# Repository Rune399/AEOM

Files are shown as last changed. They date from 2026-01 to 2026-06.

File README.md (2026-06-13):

<p align="left">
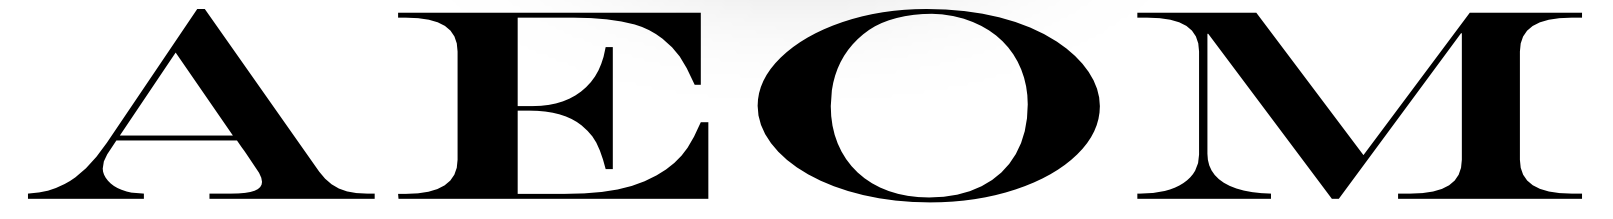
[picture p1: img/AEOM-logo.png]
  
</p> 

AEOM, de slimme interface die gezinnen helpt zonne-energie optimaal te gebruiken en hun enrgieverbruik beter te begrijpen.

🛠️ Built by ``Miro Mangelschots`` & ``Kylian Maelstaf`` & ``Rune Coppieters``  
🔥 Supervised by ``prof. dr. Bas Baccarne``, ``Yannick Christiaens`` & ``Wouter Devriese``    
🌱 Grown at ``Ghent University`` 🏛️ ``Industrial Design Engineering`` ([project overview](https://github.com/basbaccarne/human-centered-design)) 

19/01/2026   

## Samenvatting

Gebruikers hebben soms nood aan functionaliteiten die hun huishoudtoestellen niet hebben. Hoewel er steeds meer slimme apparaten op de markt komen, zijn deze vaak duur en is het vervangen van een perfect werkend toestel voor veel mensen niet de moeite waard.

Om dit probleem op te lossen werd **AEOM** ontwikkeld.

Dit project begon oorspronkelijk als een oplossing voor eigenaars van zonnepanelen die hun opgewekte energie optimaal wilden benutten. Tijdens het ontwerpproces bleek echter dat de onderliggende behoefte breder was: gebruikers willen bestaande apparaten automatiseren zonder deze te vervangen. Daarom verschoof de focus naar het slim maken van zogenaamde **"domme" apparaten**, met een specifieke focus op wasmachines en droogkasten.

### Voorbeelden van toepassingen

- Een wasmachine automatisch starten wanneer de energieprijs het laagst is.
- Een droogkast laten draaien wanneer er voldoende zonne-energie beschikbaar is.
- Een wasprogramma starten zodat het klaar is wanneer de gebruiker thuiskomt.
- Bestaande toestellen integreren in een slimme woning zonder nieuwe apparaten aan te kopen.

### De oplossing

AEOM is een modulair systeem dat fysieke knoppen en draaiknoppen van bestaande apparaten automatisch kan bedienen. Hierdoor kunnen huishoudtoestellen geautomatiseerd worden zonder aanpassingen aan het toestel zelf.

✨ Automatiseert bestaande apparaten zonder demontage.

⚙️ Bedient fysieke knoppen en draaiknoppen automatisch.

📱 Configureerbaar via een gebruiksvriendelijke applicatie.

🔔 Ondersteunt meldingen en statusupdates.

🔄 Herbruikbaar op verschillende toestellen.

Door bestaande apparaten slimmer te maken in plaats van ze te vervangen, biedt Orion een toegankelijke en duurzame manier om meer comfort, automatisering en controle in huis te brengen.
<!--Gebruikers hebben soms nood aan functionaliteit, die hun apparaten niet hebben. Nieuwe "slimme" apparaten bestaan, maar zijn vaak duur. Het is dan ook voor veel mensen niet de moeite om daarvoor een nieuwe machine te kopen. Om dat probleem op te lossen werd *AEOM* ontwikkeld.

Dit project is begonnen als oplossing voor zonnepaneel-houders, die optimaal gebruik willen maken van hun zonne-energie. 
Uiteindelijk is dat echter verandert, naar het automatiseren van "domme" apparaten. Met een focus op wasmachines en droogkasten.

>Voorbeeld van een toepassing:
>De was starten op het meest economische moment van de dag. Of op het juiste moment, zodat die klaar is wanneer de gebruiker thuis komt... 

De oplossing is een slim systeem dat apparaten aan en uit schakelt op basis van parameters, die de gebruiker instelt.

<!--Zonnepaneel-houders kunnen de goedkopere energie niet optimaal gebruiken, omdat ze overdag werken. Bestaande oplossingen zijn grote investeringen.

Dit probleem werd onderzocht aan de hand van literatuuronderzoek, interviews met de gebruikers en gebruikerstests.

De oplossing is een slim systeem dat apparaten aan en uit schakelt, op basis van de geproduceerde zonne-energie. Daarbij houd het rekening met ingestelde prioriteiten en limieten.

Het systeem regelt meerdere apparaten automatisch, waardoor de opgewekte zonne-energie optimaal kan verbruikt worden. En dat zonder de gebuiker, die zich er mee bezig moet houden.

>:bulb:Voor simpele apparaten, worden slimme pluggen geintegreerd. Hiervoor worden bv. de bestaande pluggen van [Shelly](https://www.shelly.com/products/shelly-plug-s-gen3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) gebruikt.

>:zap:Voor complexere apparaten, zoals wasmachines, wordt een nieuw onderdeel ontwikkelt. De bedoeling van dat onderdeel is om draaiknoppen en touchscreens te kunnen bedienen.

<p align="center">
  <img src="img/Hero1.png" width="100%">
</p>-->
<p align="center">
  
</p>

## Introductie

De opkomst van hernieuwbare energie, zoals zonnepanelen, zorgt voor nieuwe uitdagingen in huishoudelijk energiegebruik. Hoewel energie lokaal wordt geproduceerd, slagen gebruikers er vaak niet in om hun verbruik af te stemmen op deze productie, wat leidt tot inefficiëntie en verlies van potentieel voordeel.

Bestaande oplossingen, zoals slimme toestellen, vereisen doorgaans een aanzienlijke investering en vervangen bestaande apparaten. Dit maakt ze voor veel gebruikers minder toegankelijk.

AEOM vertrekt vanuit een alternatieve benadering: het slim maken van bestaande, “domme” toestellen via een externe interface. Door apparaten automatisch aan te sturen op basis van parameters zoals energieproductie, kost en gebruikscontext, maakt AEOM efficiënter en bewuster energiegebruik mogelijk zonder ingrijpende veranderingen in de bestaande huishoudcontext.

Dit dossier beschrijft hoe dit concept tot stand kwam, met nadruk op de onderbouwing van ontwerpkeuzes via gebruikersonderzoek, iteratie en technische validatie.

## Inhoudstafel

1. [Methodologie](./docs/Methodologie.md)
2. [Discovery](./docs/1_Discovery.md)
3. [Defintion](./docs/2_Definition.md)
4. [The pivot](./docs/3.1_The_Pivot.md)
5. [Develop 1](./docs/3_Develop_1.md)
6. [Develop 2](./docs/4_Develop_2.md)
7. [Develop 3](./docs/5_Develop_3.md)
8. [Design Requirements](./docs/Design_requirements.md)
9. [Bill of materials](./docs/BOM.md)
10. [Handleiding voor laatste prototype](./docs/Manual.md)

# Conclusie

Tijdens dit project werd onderzocht hoe bestaande huishoudtoestellen slimmer gemaakt kunnen worden zonder deze te vervangen. Uit gebruikersinterviews, benchmarkonderzoek, technische experimenten en meerdere iteraties van prototyping bleek dat veel gebruikers nood hebben aan extra functionaliteiten, zoals automatisering en slim energiebeheer, maar niet bereid zijn om hiervoor nieuwe toestellen aan te kopen.

Het finale concept, **AEOM**, is een universeel automatiseringsplatform dat fysieke knoppen en draaiknoppen van bestaande apparaten automatisch kan bedienen. Hierdoor kunnen toestellen zoals wasmachines en droogkasten geïntegreerd worden in slimme automatiseringsscenario's zonder enige aanpassing aan het toestel zelf.

Het concept bestaat uit een positioneerbare arm die zich naar de gewenste knop beweegt en deze fysiek bedient. Via een mobiele applicatie kan de gebruiker toestellen configureren, automatiseringen instellen en meldingen ontvangen. Hierdoor wordt functionaliteit toegevoegd aan bestaande apparaten, terwijl hun oorspronkelijke werking volledig behouden blijft.

Wij geloven dat **AEOM** de best mogelijke oplossing is voor het gestelde probleem omdat het verschillende voordelen combineert die tijdens het onderzoek consequent als belangrijk naar voren kwamen:

- Geen vervanging van bestaande toestellen nodig.
- Compatibel met een brede waaier aan huishoudtoestellen.
- Eenvoudig te installeren zonder demontage of technische kennis.
- Herbruikbaar op verschillende apparaten.
- Lagere kost dan de aankoop van nieuwe slimme toestellen.
- Behoud van volledige controle door de gebruiker.
- Mogelijkheid om toekomstige functionaliteiten via software uit te breiden.

Bovendien werden gedurende het ontwikkelproces verschillende alternatieve oplossingen onderzocht, waaronder slimme stekkers, vaste interfaces, meerdere actuatorconfiguraties, verschillende bevestigingsmethoden en uiteenlopende positioneringsmechanismen. De uiteindelijke combinatie van een **sliding & rotating arm**, een **servogestuurde knopbediening** en een **modulaire mobiele interface** behaalde consequent de beste resultaten op vlak van gebruiksgemak, betrouwbaarheid, universaliteit en gebruikersacceptatie.

De ontwerpkeuzes zijn gebaseerd op de verzamelde onderzoeksresultaten en voldoen aan de vooropgestelde [Design Requirements](./Design_Requirements.md). Hierdoor vormt **AEOM** een technisch haalbare, gebruiksvriendelijke en toekomstgerichte oplossing voor het automatiseren van bestaande huishoudtoestellen.

<p align="center">
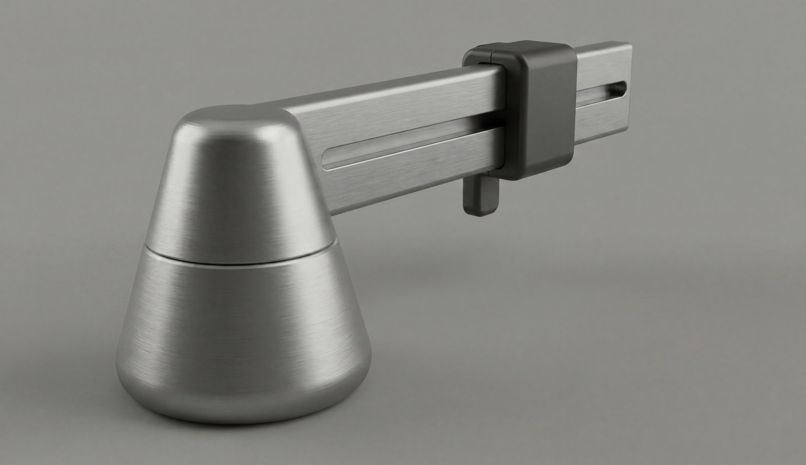
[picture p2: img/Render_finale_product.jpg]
  
</p>

## Kritische reflectie

Bij de define fase bleek het een uitdaging te zijn, om ons op het juiste pad te houden en niet de mist in te wandelen. We vergaten soms dat de in de define fase zaten, waar het de bedoeling is om oplossingen voor het probleem te zoeken.

We hebben eerst onderzoek gedaan naar de meest intuitieve layout van een scherm-interface. Dit onderzoek had bij nader inzien beter gepast bij de develop fase.
In het komende semester zal het dus belangrijk zijn voor ons om elke les even stil te staan en de vraag te stellen, of wat we mee bezig zijn nog past binnen deze fase...

Bovendien hebben we veel tijd verloren, door in de les te bespreken wat de volgende stappen zijn, waardoor we meerdere, hele lessen weinig hebben gedaan, buiten overlegd. 
Op een bepaald moment twijfelden we over de richting waarin we gingen, we stonden op het punt om een pivot te ondergaan, maar hebben dat uiteindelijk niet gedaan. De oorzaak van deze twijfel was waarschijnlijk dat we juist het interface-onderzoek hadden uitgevoert, dat eigenlijk voor het volgende semester was bedoeld. Door deze pseudo-pivot zijn opniew veel tijd verloren.
Hierdoor hadden we het gevoel dat we heel de tijd achter zaten (wat ook wel zo was) en hebben we ook geen tijd meer gehad om een een tweede onderzoek te doen dat wel goed in de define fase hoort... 

## Noot inzake het gebruik van AI
Om schetsen om te zetten in renders werd "[Vizcom](https://vizcom.com)" gebruikt (o.a. [Hero-shot](img/Hero1.png)).
AI werd ook gebruikt om sommige onderzoeken te verwerken. Hierbij werd opgelet dat **alle info geanonimiseerd** werd **alvorens** AI in te zetten.

## Bijlagen

### Discovery
* Literatuuronderzoek (N=10)
  * [Benchmark protocol](reports%20and%20protocols/S@H_Benchmark%20protocol.pdf)
  * [Benchmark report](reports%20and%20protocols/S@H_Benchmark%20report.pdf)
* Interviews (N=3)
  * [User interview protocol](reports%20and%20protocols/S@H_User%20Interview%20Protocol.pdf)
  * [User interview report](reports%20and%20protocols/S@H_User%20interview%20report.pdf)
    
### Definition
* User testing wave 1 (N=3)
  * [Interface protocol](reports%20and%20protocols/Interface%20protocol.pdf)
  * [Interface repport](reorts%20and%20protocols/Inteface%20report.pdf)
* User testing wave 2 (N=3)
  * [Functies protocol](reports%20and%20protocols/Functies%20protocol.pdf)
  * [Functies repport](reports%20and%20protocols/Functies%20report.pdf)

### Develop 1
* User interview (N=3)
  * [Interview after pivot protocol](reports%20and%20protocols/Interface%20protocol.pdf)
  * [Interview after pivot repport](reports%20and%20protocols/Inteface%20report.pdf)
* Prototype testing (N=~5)
  * [Drukken van knoppen protocol](reports%20and%20protocols/Functies%20protocol.pdf)
  * [Drukken van knoppen report](reports%20and%20protocols/Functies%20report.pdf)

### Develop 2
* Draaien van knoppen (N=3)
  * [Draaien van knoppen protocol](reports%20and%20protocols/2.%20Draaien%20van%20knoppen%20protocol.pdf)
  * [Draaien van knoppen report](reports%20and%20protocols/2.%20Draaien%20van%20knoppen%20report.pdf)
* Machine interface (N=10)
  * [Machine interface protocol](reports%20and%20protocols//4.%20Machine%20interface%20protocol.pdf)
  * [Machine interface report](reports%20and%20protocols//4.%20Machine%20interface%20report.pdf)
* Gebruikersonderzoek (N=5)
  * [Gebruikersonderzoek protocol](reports%20and%20protocols/5.%20Gebruikersonderzoek%20protocol.pdf)
  * [Gebruikersonderzoek report](reports%20and%20protocols/5.%20Gebruikersonderzoek%20report.pdf)
* Bevestigingsmechanismen (N=3)
  * [Bevestigingsmechanismen protocol](reports%20and%20protocols/2.%20Bevestigingsmechanismen%20protocol.pdf)
  * [Bevestigingsmechanismen report](reports%20and%20protocols/2.%20Bevestigingsmechanismen%20report.pdf)
    
### Develop 3
* CMF (N=5)
  * [CMF protocol](reports%20and%20protocols/6.CMF_protocol.pdf)
  * [CMF report](reports%20and%20protocols/6.CMF_report.pdf)

## Licentie

This repository contains both software and design materials created as part of an industrial design energineering project at Ghent University.

- **Software and code:** [MIT License](./LICENSE-MIT)  
- **Design, documentation, CAD, and media:** [CC BY 4.0 License](./LICENSE)
  
You are free to reuse and build upon this work, both commercially and non-commercially, as long as proper attribution is given to the original authors.

<br>

---

<p align="center">
  <a href="/README.md">⬆️ Return to top</a><br>
  <a href="/LICENSE">📜 CC License</a> & <a href="/LICENSE">MIT License</a><br>

</p>

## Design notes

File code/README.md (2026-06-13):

## Code structuur

Deze map bevat de Arduino implementaties voor de aansturing van de verschillende mechanische concepten.  

### **Servo_and_Stepper_code**  
  Code voor de **sliding + rotating arm**  
  - Combineert een **servo motor** (rotatie) met een **stepper motor** (lineaire beweging)  
  - Zorgt voor positionering van de arm in zowel hoek als afstand  
  - Wordt gebruikt voor de finale geselecteerde oplossing  
<p align="left">
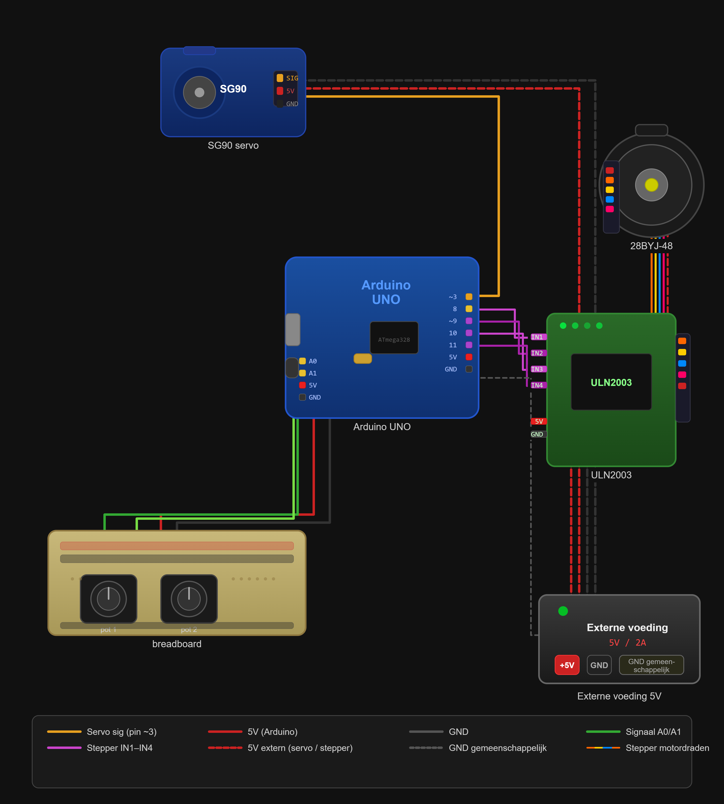
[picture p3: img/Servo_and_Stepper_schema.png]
  
  
### **Servos_code**  
  Code voor de **double pivot arm**  
  - Gebruikt meerdere **servo motoren** voor de verschillende rotatiepunten  
  - Stuurt de arm aan via gecombineerde hoeken (inverse kinematics)  
  - Wordt gebruikt voor het alternatieve concept dat later geëlimineerd werd
    <p align="left">
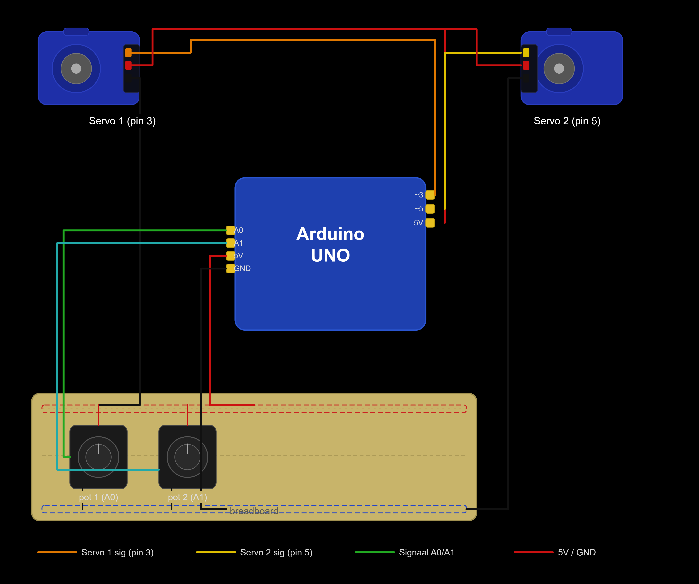
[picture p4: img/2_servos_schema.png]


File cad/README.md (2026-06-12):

## CAD structuur

De CAD-bestanden zijn georganiseerd per mechanisme en per iteratiefase. Dit maakt het mogelijk om de evolutie van het ontwerp en de verschillende prototypes duidelijk te onderscheiden.  

### Opbouw  

- **cad/**  
  Hoofdmap met alle CAD-bestanden  

  - **rotating pivot arm/**  
    Ontwerpen van het rotating pivot arm mechanisme  

    - **V1/**  
      Eerste generatie prototypes  
      → Snelle exploratie van concept en werking  

    - **V2/**  
      Tweede generatie prototypes  
      → Verbeterde ontwerpen op basis van testen (stabiliteit, haalbaarheid, gebruik)  

    - **arm_close.3mf**  
      Configuratie waarbij de arm dicht bij het centrum staat  

    - **arm_far.3mf**  
      Configuratie waarbij de arm maximaal is uitgeschoven  

    - **base.3mf**  
      Basismodel van de structuur waarop de arm gemonteerd wordt  

    - **fullprint.3mf**  
      Volledige samenstelling, klaar voor 3D-print  

    - **test belt afstanden.3mf**  
      Testmodel om verschillende riemafstanden en transmissies te evalueren  

  - **rotating slider arm/**  
    Ontwerpen van het sliding + rotating arm mechanisme  

    - **V1/**  
      Eerste generatie prototypes  
      → Initiële exploratie van sliding mechanisme  

    - **V2/**  
      Tweede generatie prototypes  
      → Geoptimaliseerde ontwerpen gebaseerd op testen en iteraties

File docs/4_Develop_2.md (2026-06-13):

## Develop 2

### Doelstellingen
In de vorige de develop 1 fase werd een schema met human-product-interactie's opgesteld. Daar werd ook voor elke subfunctie oplossingen bedacht.

In deze fase moet verder onderzoek en tests gedaan worden om de beste deeloplossingen te selecteren.

Er wordt ingegaan op volgende deelfuncties:
- Draaien van knoppen
- Machine interface =  instellen van de interactie-locatie
- Bevestigingsmechanismen
<br><br><br>
### Methoden
#### 1. Draaien van knoppen
Bij het besturen van een draaiknop komen er twee hoofdzaken naar boven:
•	Welke actuator zullen we gebruiken?
•	Hoe gaan we de draaiknop manipuleren?
<br><br>

##### Actuator
<p align="left">
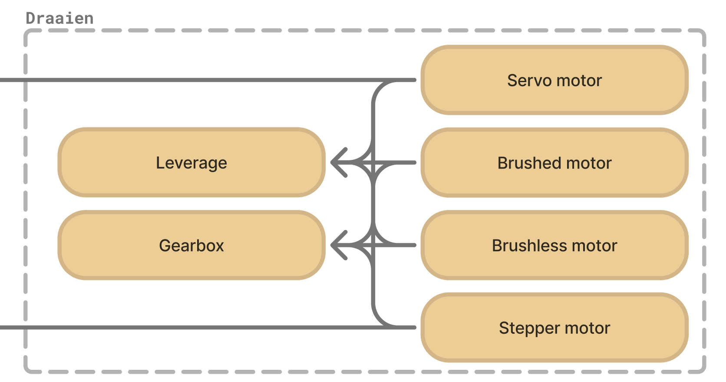
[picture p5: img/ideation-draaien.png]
  
</p>

1.	Ideeën generatie actuatoren
2.	De resultaten van vorig onderzoek, die nuttig zijn, worden gebruikt om actuatoren te elimineren
3.	Kracht servo apart uittesten op de knop*
4.	Er wordt één finale actuator gekozen

> [!NOTE]
>*Een servo is eigenlijk opgebouwd uit een geborstelde DC motor en tandwielkast met toevoeging van één of andere sensor.
>Omdat die feedback van een sensor in deze toepassing belangrijk is, zou het makkelijker zijn, om de servo te gebruiken. Daarvoor moet de servo echter sterk genoeg zijn om de knop te kunnen draaien. Voor die reden wordt de servo nog eens apart uitgetest op de knop.

<br>

##### Manipulatie draaiknop
<p>
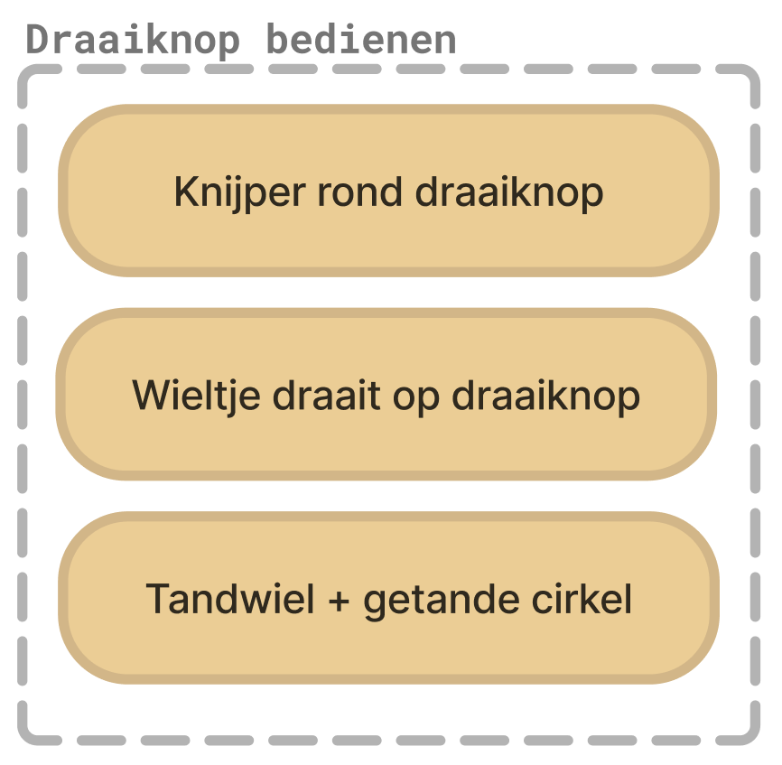
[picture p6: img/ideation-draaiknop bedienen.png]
  <br>1.	Ideeën generatie om de knop te kunnen manipuleren<br>
  2.	Er worden prototypes gemaakt voor de verschillende ideeën<br>
  3.	De prototypes worden uitgetest op de draaiknop van een wasmachine (beiden worden aangestuurd met hetzelfde handvat)<br>
  4.	De voordelen en nadelen van elk idee worden opgesomd<br>
  5.	De ideeën worden vergeleken en er wordt één idee uitgekozen<br>
  <br>
  Voor meer detail over dit onderzoek of een blik op de gebruikte prototypes, zie <a href="../reports and protocols/2. Draaien van knoppen protocol.pdf">Draaien van knoppen protocol</a>.
</p>
<br clear="left" />
<br><br>

#### 2. machine interface onderzoek
<p align="left">
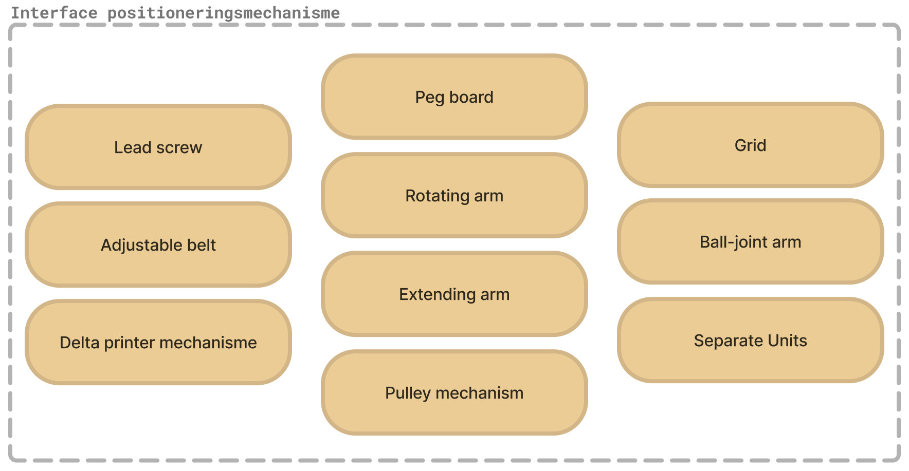
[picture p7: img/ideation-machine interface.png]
  
</p>
  
#### Deel 1: eerste eliminatie.
De ideeën worden vergeleken via een keuzematrix
<br>
#### Deel 2: prototype + vergelijkend testen.
1.  Er worden prototypes gemaakt voor de overblijvende ideeën
2.  De prototypes worden op een wasmachine geplaatst om te testen of het systeem aan alle nodige knoppen kan
  
#### Deel 3: technisch uitwerking + gebruikerstesten.
1.  De prototypes worden verder uitgewerkt tot meer afgewerkte versies
2.  De prototypes worden ingezet in een Wizard of Oz testing met gebruikers (N = 5)
3.  De oplossingen worden vergeleken en er wordt één mechanisme geselecteerd

Tijdens de Wizard of Oz testing wordt ook geëvalueerd hoe gebruikers de arm kunnen instellen, waarbij per ontwerp en per methodiek wordt nagegaan hoe intuïtief en efficiënt de sturing verloopt.  
Elke gebruiker voert volgende taken uit:  
- Instellen van de arm met sliders  
- Instellen van de arm met joystick  
- Aanduiden van een knop via een foto  

De interface waarop deze methodes getest worden is hier terug te vinden:  
https://peppy-sprinkles-e374be.netlify.app/  

Na elke test wordt een SUS (System Usability Scale) ingevuld per methodiek en per ontwerp.  
Op het einde volgt een kort interview (QAP) om aanvullende inzichten en opmerkingen te verzamelen.

Voor meer detail over dit onderzoek of een blik op de gebruikte prototypes, zie <a href="../reports%20and%20protocols/4.%20Machine%20interface%20protocol.pdf">Machine interface protocol</a> en <a href="../reports%20and%20protocols/5.%20Gebruikersonderzoek%20Protocol.pdf">Gebruikersonderzoek protocol</a>.

<br><br>
#### 3. bevestigingsmechanismen
<p align="left">
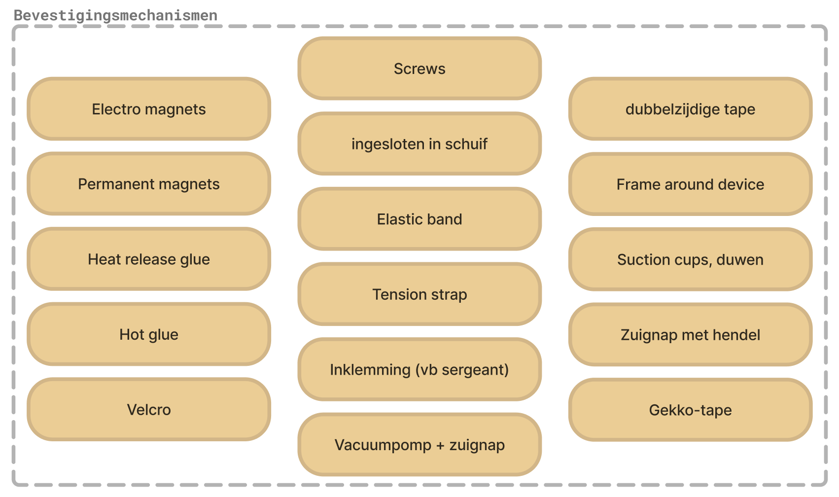
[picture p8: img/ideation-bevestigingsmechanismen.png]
  </p>
  
##### Deel 1: eerste intuïtieve eliminatie.

##### Deel 2: prototyping + vergelijkend testen.
1.	Modulair prototypen
2.	Op wasmachine hangen
3.	Met weegschaal aan het prototype trekken tot het los komt
4.	Filmen bij hoeveel kg kracht het bevestigingsmechanisme lost
5.	Maximale kracht opmeten voor trek en moment voor elke oplossing
6.	Per oplossing 4 tests uitvoeren: 2x trek & 2x moment
7.	Tabel opstellen en gemiddeldes van trek en moment per oplossing berekenen
8.	Grafiek opstellen

Voor meer detail over dit onderzoek of een blik op de gebruikte prototypes, zie <a href="../reports and protocols/2. Bevestigingsmechanismen protocol.pdf">Bevestigignsmechanismen protocol</a>.

<br clear="left" />

### Resultaten
#### 1. Draaien van knoppen

##### a. Vergelijking actuatoren
||Kracht|Gewicht|Gemak aansturing|Feedbackloop|
|--:|:--:|:--:|:--:|:--|
|**Servo**|Matig|Matig|Matig|Ja => hoge precisie + herhaalbaarheid|
|**Stepper**|Matig|Zwaar|Moeilijk|Nee (Maar hoge precisie + herhaalbaarheid, bij geen slip)|
|**Brushed + gearbox**|Zeer hoog|Zwaar|Makkelijk|Nee|

> [!NOTE] 
>stepper niet uitgetest op machine #TODO

##### b. Extra servo test

><a href="../reports and protocols/3. Bevestigingsmechanismen protocol.pdf"><b>Servo_draaien knoppen.mp4</b></a><br>
>De servo had niet genoeg kracht om zelfstandig te knop te draaien, maar er was niet veel extra kracht vereist. Er werd niet getest met een sterkere servo-motor, maar er kan vanuit gegaan worden dat grotere servo-motoren wel de knop zouden kunnen draaien.

##### c. Pros & Cons manipulatie draaiknop
###### Knijper rond draaiknop
<p >
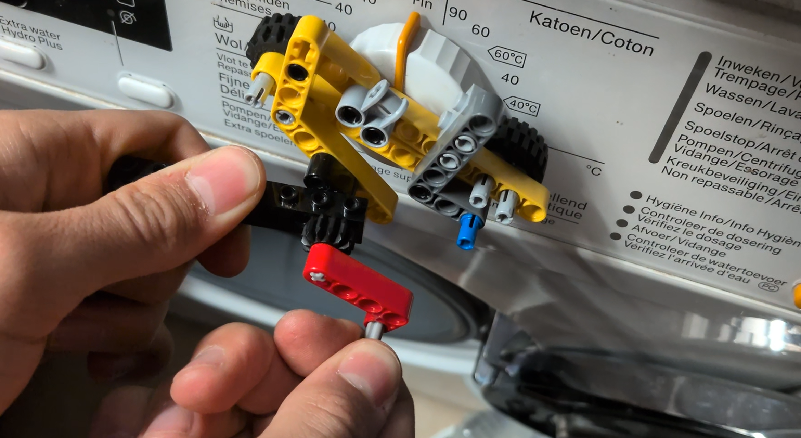
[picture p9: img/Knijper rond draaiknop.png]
  
</p>

✅ Er is veel grip door de instelbare klemkracht<br>
✅ Geen perfect ronde vorm nodig<br>
✅ Uitstekende vormen zijn geen probleem<br>
✅ Eenvoudige constructie<br>

❌ Er is meer kracht nodig dan de andere concepten omdat er geen overbrenging aanwezig is (as motor = as knijper, zonder overbrenging)<br>

<br clear="left" />

###### Wieltje tegen draaiknop
<p >
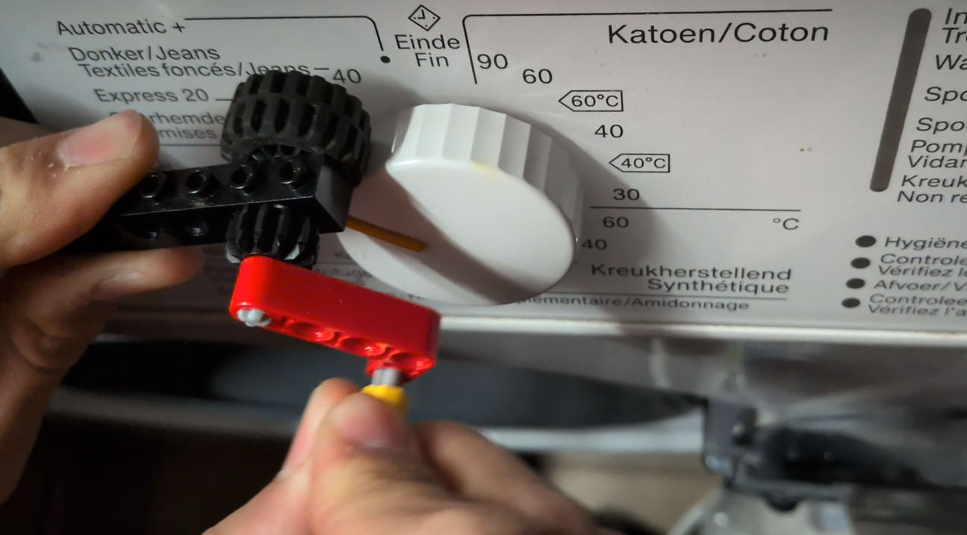
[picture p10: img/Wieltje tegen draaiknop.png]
  
</p>

✅ Voordelige overbrenging, die de nodige kracht van de motor verminderd: door het verschil in diameter tussen het kleine wieltje en de grotere draaknop verminderd de aandrijfkracht.<br>
✅ Het is een zeer compacte oplossing<br>
✅ Eenvoudige constructie en montage<br>

❌ Weinig grip, waardoor er slip aanwezig is en de draaiknop **onbetrouwbaar of niet zal roteren**<br>
❌ **Werkt enkel** goed **met één vorm**: een perfect ronde cirkel, zonder uitstekende delen<br>

<br clear="right" />

###### Vertanding op draaiknop met een tandwiel
<p>
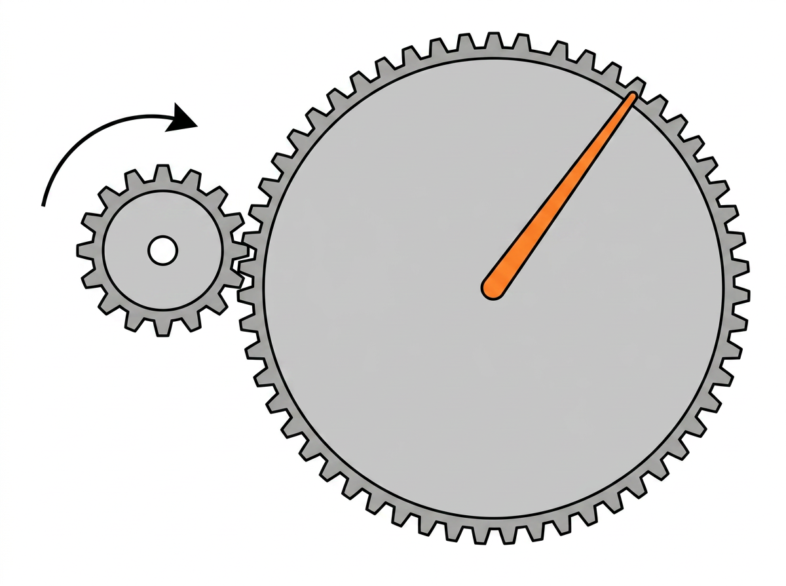
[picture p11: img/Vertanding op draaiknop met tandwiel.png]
  
</p>

✅ Er is een overbrenging aanwezig wat de nodige kracht van de motor verminderd.<br>
✅ Het is een compacte oplossing<br>

❌ Kans op slip tussen tandwielring en draaiknop<br>
❌	Niet zo universeel:<br>
-→ ❌ Werkt enkel goed met één vorm: een perfect ronde cirkel<br>
-→ ❌ Uitstekende delen van de draaiknop zorgen voor problemen<br>
-→ ❌ Verschil in knopdiameter tussen toestellen zorgt voor compatibiliteitsproblemen<br>
<br clear="left" />
<br><br>

#### 2. Machine interface onderzoek

##### a. Eerste eliminatie

|  | || **Peg board** | **Grid** | **Sliding + rotating arm** | **Rotating pivot arm** | **Lead screw carriage** | **Rail + slide carriage** | **Seperate units** | **Standing carriage** | **Spider arms** |
|:---:|:---:|:--:|:---:|:---:|:---:|:---:|:---:|:---:|:---:|:---:|:---:|
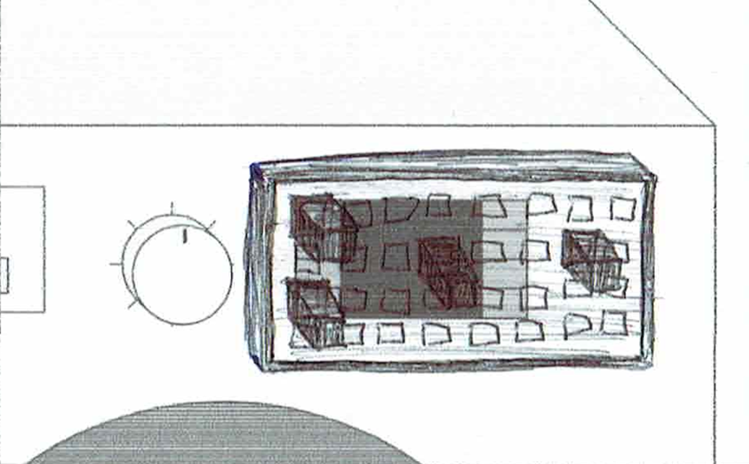
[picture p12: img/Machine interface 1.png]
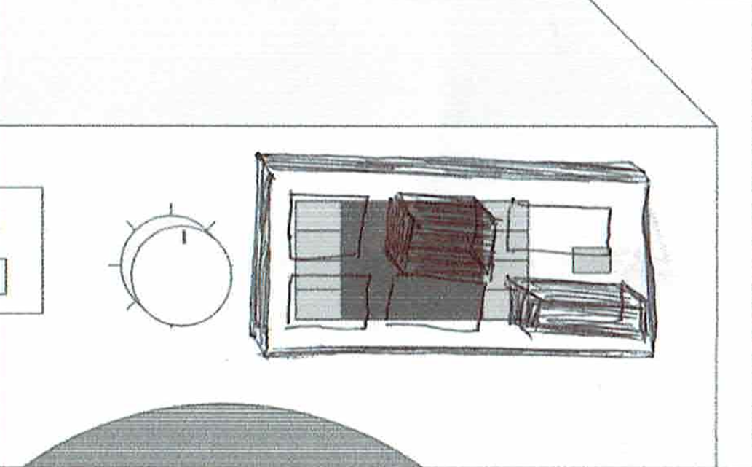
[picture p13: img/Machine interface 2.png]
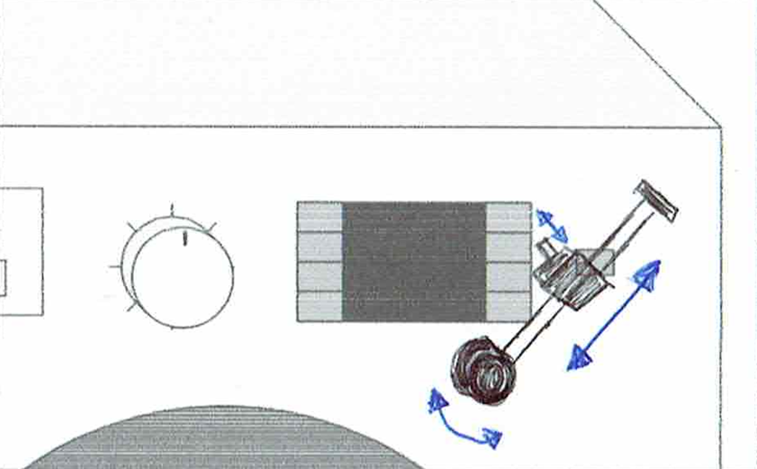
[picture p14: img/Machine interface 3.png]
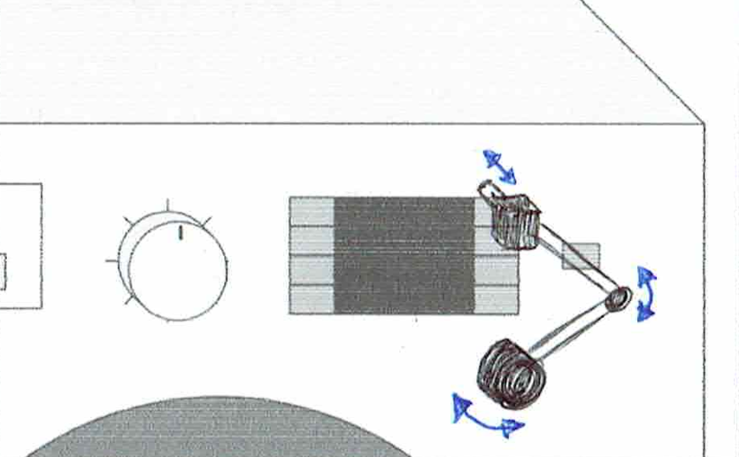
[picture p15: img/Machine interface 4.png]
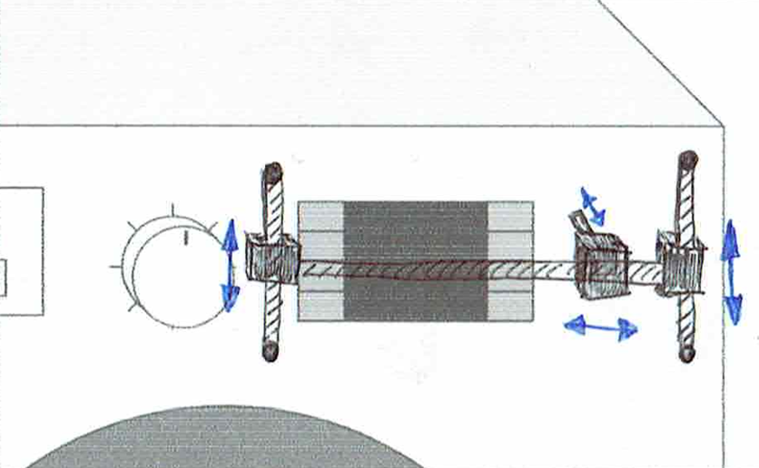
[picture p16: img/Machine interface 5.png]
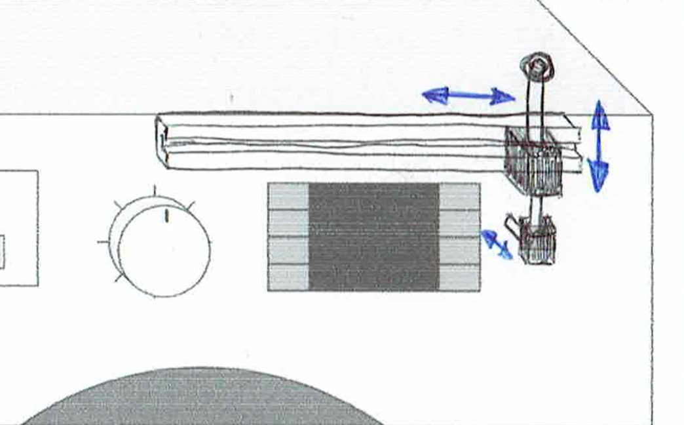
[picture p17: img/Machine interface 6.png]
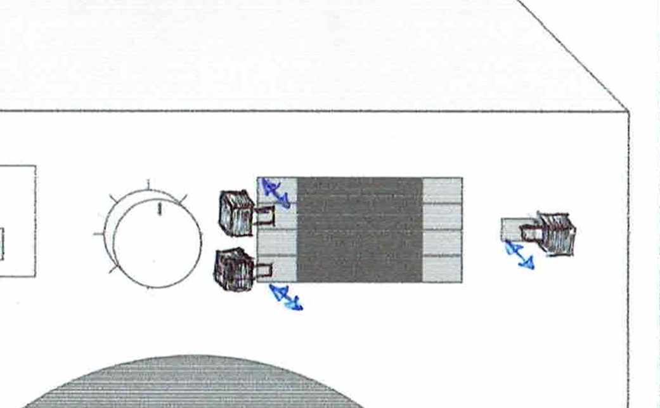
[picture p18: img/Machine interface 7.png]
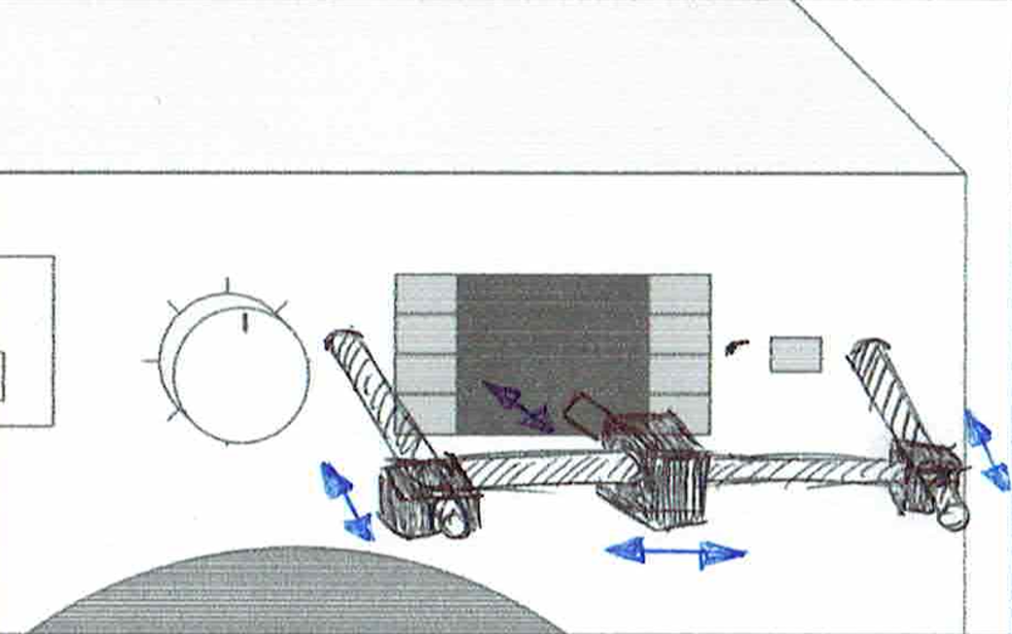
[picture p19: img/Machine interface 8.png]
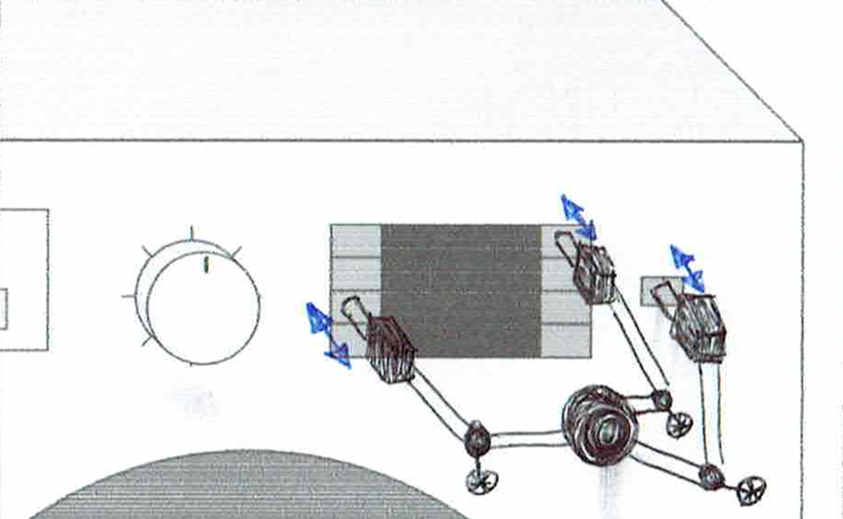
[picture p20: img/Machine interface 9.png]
|**Criteria**<br>v v v|**Gewicht**<br>v v v ||  |  |  |  |  |  |  |  |  |
| **Breedte** | 3 || -2 | -2 | -1 | 1 | -2 | -2 | 2 | -1 | -1 |
| **Diepte** | 3 || 2 | 2 | 1 | 1 | 0 | 0 | 2 | -2 | -1 |
| **Stabiliteit** | 3 || 2 | 2 | -1 | -2 | 2 | 1 | 2 | -2 | -1 |
| **Nauwkeurigheid** | 3 || -1 | -2 | 2 | 2 | 2 | 2 | -1 | 2 | -1 |
| **Complexiteit aansturing** | 1 || 2 | 2 | 0 | -2 | 0 | 0 | 2 | 0 | 2 |
| **Setup** | 3 || 0 | 0 | 1 | 2 | -1 | 0 | 0 | -1 | -1 |
| **Complexiteit ontwerp** | 1 || 2 | 2 | -1 | -1 | 0 | 1 | 2 | -1 | -2 |
| **Universaliteit** | 3 || 1 | 1 | 2 | 2 | 1 | 1 | 1 | 0 | 1 |
| **Transparantie** | 3 || -2 | -2 | 1 | 2 | 0 | 1 | 2 | 0 | 0 |
| **Totaal** | || 4 | 1 | <mark><b>14</mark> | <mark><b>21</b></mark> | 6 | 10 | <mark><b>28</b></mark> | -13 | -12 |

>[!Tip]
>Klik op de afbeeldingen in de tabel, om ze te vergroten.

<br>

##### b. Tweede eliminatie
<p>
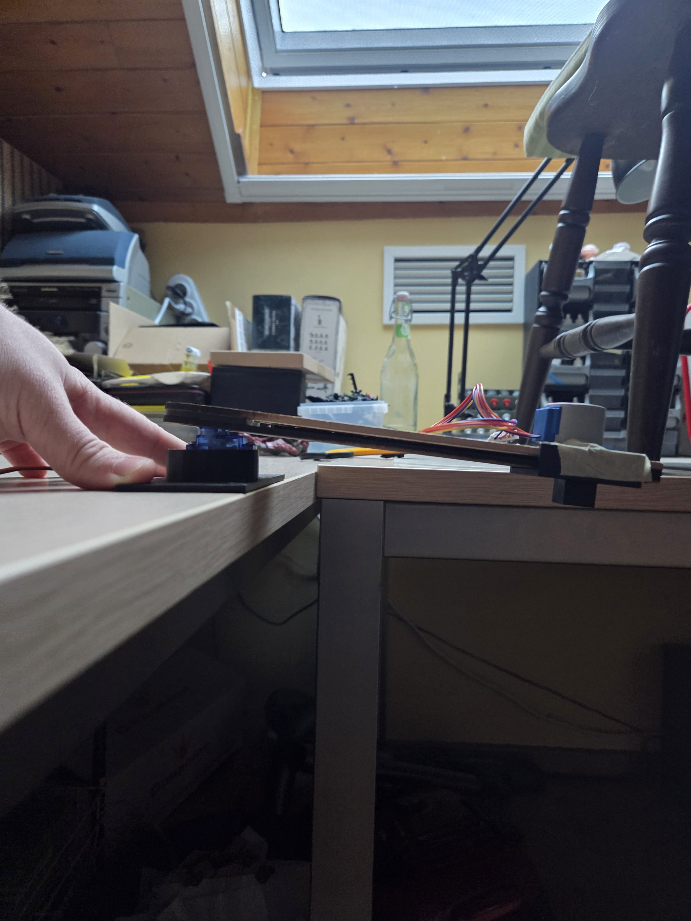
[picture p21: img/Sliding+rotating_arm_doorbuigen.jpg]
  
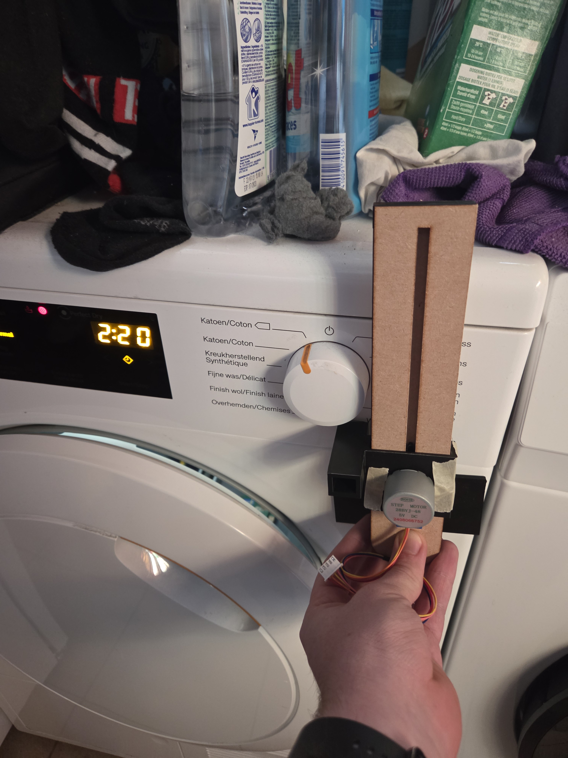
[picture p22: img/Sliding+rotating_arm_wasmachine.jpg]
  
</p>

- **Sliding + rotating arm**  
  ✅ Compacte plaatsing rond de interface mogelijk  
  ❌ Instabiel door lange armen en gewicht van componenten  
  ❌ Groot systeem dat knoppen deels afdekt  
  ❌ Beperkte compatibiliteit door afmetingen  

<br clear="all">

<p>
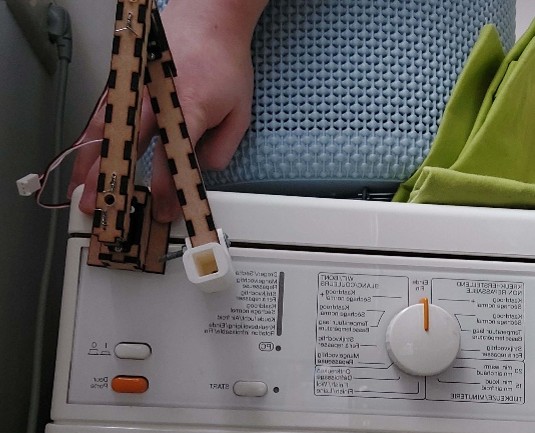
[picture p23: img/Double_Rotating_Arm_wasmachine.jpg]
  
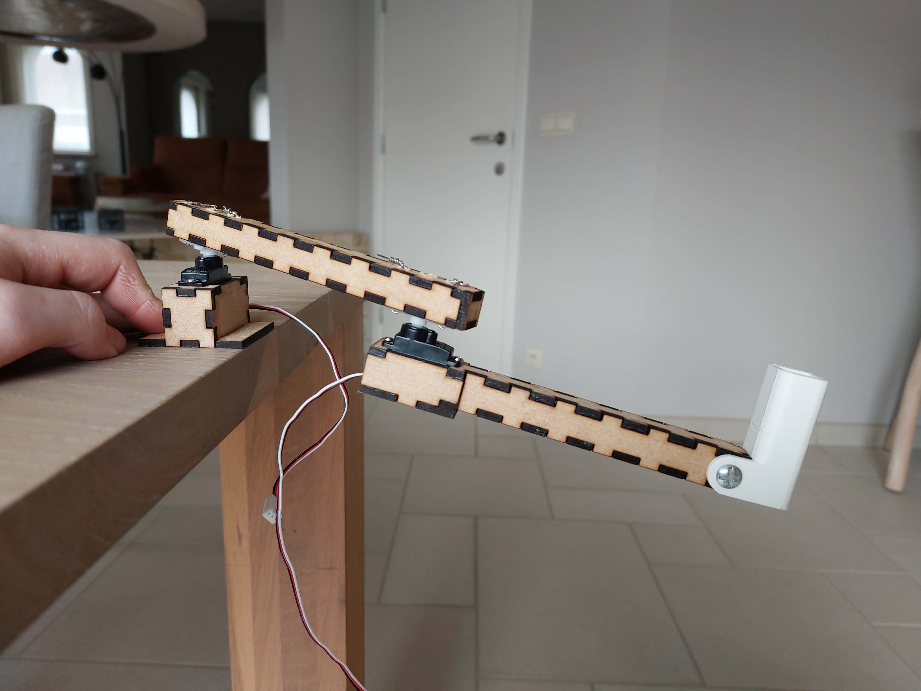
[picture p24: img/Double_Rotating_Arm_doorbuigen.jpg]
  
</p>

- **Rotating pivot arm (double rotating arm)**  
  ✅ Inklapbaar, dus betere transparantie  
  ✅ Flexibele positionering  
  ❌ Instabiliteit door meerdere scharnierpunten  
  ❌ Nog relatief groot systeem  

<br clear="all">

<p>
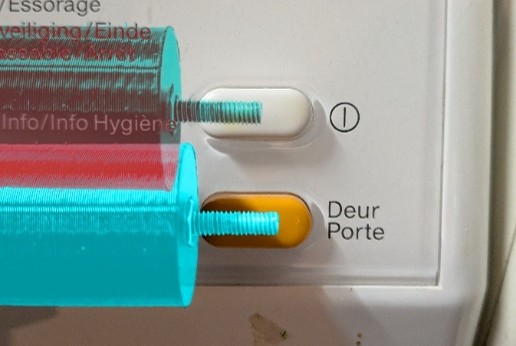
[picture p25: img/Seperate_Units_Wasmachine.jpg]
  
</p>

- **Separate units**  
  ✅ Goede stabiliteit per unit  
  ❌ Veel units nodig → hoge kost  
  ❌ Moeilijk te plaatsen bij dicht opeenstaande knoppen  
  ❌ Verminderde overzichtelijkheid en universaliteit  

<br clear="all">

<br>

#### c. Derde eliminatie
<p>
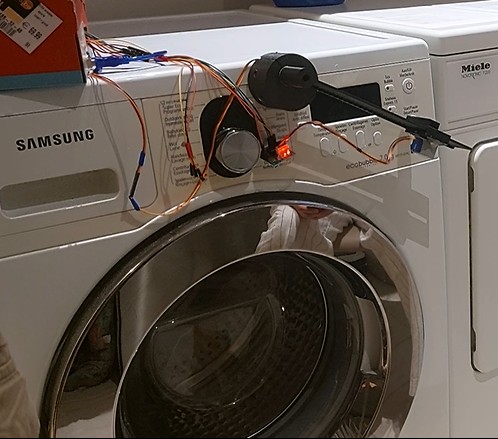
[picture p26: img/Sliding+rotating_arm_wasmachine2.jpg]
  
</p>

- **Sliding + rotating arm**  
  ✅ Intuïtieve en voorspelbare beweging  
  ✅ Gemakkelijker te begrijpen voor gebruikers  
  ✅ Minder complexe aansturing  
  ❌ Sliding beweging relatief traag  
  ❌ Vereist homing sequentie  

<br clear="all">

<br>
<p>
  
</p>

- **Rotating pivot arm (double pivot arm)**  
   ✅ Kan compacter bewegen tussen knoppen  
   ❌ Minder intuïtief in gebruik  
   ❌ Onvoorspelbare bewegingen  
   ❌ Complexe berekeningen nodig (inverse kinematics) 

<br clear="all">

#### Sturing van het product  
**SR:** sliding + rotating arm  
**RR:** double pivot arm  

<p align="center">
  
</p>

<p align="center">
  
</p>

>[!Warning]
> *Note 1:* Bij de foto methode werd enkel de input tot bevestiging gemeten. Tijd is minder relevant omdat de focus op de arm ligt.  
> *Note 2:* De sliding beweging van de sliding + rotating arm is traag, waardoor de tijden hoger liggen dan in realiteit.  
> *Note 3:* Startpositie beïnvloedt de tijd sterk; bij een gunstige positie kan een knop zeer snel bereikt worden.  

<br>

#### 3. Bevestigingsmechanismen
##### a. Beargumenteerde intuïtieve eliminatie
|Idee	|Richt geen schade aan	|Praktisch monteren	|Praktisch voor ontwerp	|Resultaat|
|--:|:--:|:--:|:--:|:--:|
|Electro magneet	|✅	|✅	|❌	|❌
|Permanente magneet	|✅	|✅	|✅	|✅|
|Smeltlijm	|✅/❌	|✅	|✅	|❌|
|Hot glue	|✅/❌	|❌	|✅	|❌|
|Velcro	|✅	|✅	|✅	|✅|
|Gekko-tape	|✅	|✅	|✅	|✅|
|Dubbelzijdige tape	|✅	|✅	|✅	|✅|
|Frame rond wasmachine	|✅	|❌	|❌	|❌|
|Schroeven	|❌	|❌	|✅	|❌|
|Ingesloten in sleuf	|✅	|✅	|❌	|❌|
|Rekker	|✅	|❌	|✅	|❌|
|Ratchet strap	|✅	|❌	|✅	|❌|
|Inklemming (vb sergeant)	|✅	|❌	|❌	|❌|
|Zuignap + vacuumpomp	|✅	|✅	|❌	|❌|
|Zuignap	|✅	|✅	|✅	|✅|
|Zuignap met hendel	|✅	|✅	|✅	|✅|

##### b. Prototyping + vergelijkend testen
<!---
||Magneten	|Dubbelzijdige tape	|Gekko tape	|Zuignappen	|Hendel zuignap|
|--:|:--:|:--:|:--:|:--:|:--:|
|**Moment 1**	|0,58	|~~2,17~~ => 4,67	|3,88	|0,33	|1,53|
|**Moment 2**	|0,57	|4,64	|3,87	|0,46	|1,80|
|**Trek 1**	|4,02	|~~4,65~~ => 16,90	|15,99	|2,82	|15,67|
|**Trek 2**	|3,73	|11,11	|17,71	|3,99	|15,22|
|**Moment gem**	|0,575	|3,405	|3,875	|0,395	|1,665|
|**Trek gem**	|3,875	|7,88	|16,85	|3,405	|15,22|
-->

<p align="center">
  
</p>

>[!Warning]
>Bij deze resultaten is het belangrijk om rekening te houden dat de hendel zuignap een kleinere diameter heeft dan andere prototypes (55mm i.p.v. 65mm). Dat zorgt voor een 1.375 keer kleinere oppervlakte dan bij de andere tests.

<br>

### Conclusies & implicaties
#### 1. Draaien van knoppen

- De knijper is de beste oplossing, om de draaiknop aan te sturen.

- Voor het draaien van een wasmachine-knop, krijgtr de servomotor de voorkeur.

#### 2. Machine interface onderzoek
- De sliding + rotating arm is de beste oplossing om de juiste knop op de interface te positioneren

- De foto methode is de beste oplossing, om de gewenste knop op een intuïtieve manier in te stellen.

#### 3. Bevestigingsmechanismen
Als finale conclusie wordt gesteld dat de gekko- of nanotape de beste optie is voor het monteren van een knoppendrukker, op een wasmachine.

<br>

---

<p align="center">
  <a href="/Develop 2">⬆️ Return to top</a><br>
  <a href="">🏠 Return to main<a><br>
  <a href="/LICENSE">📜 CC License</a> & <a href="/LICENSE">MIT License</a><br>

</p>

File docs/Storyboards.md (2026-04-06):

Storyboard setup
Storyboard SETUP
Storyboard in use
Storyboard IN USE

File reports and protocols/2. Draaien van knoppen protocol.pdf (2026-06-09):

# Draaien van knoppen protocol

### Sustainability @ Home

Onderzoekers:
Miro Mangelschots - Student Industrieel Ingenieur Industrieel Ontwerpen 2e bachelor Rune Coppieters - Student Industrieel Ingenieur Industrieel Ontwerpen 3e bachelor Kylian Maelstaf - Schakelstudent Industrieel Ingenieur Industrieel Ontwerpen

# Kadering en doelstelling

Dit project richt zich op het automatiseren van “domme” apparaten.
Het product-concept werd eerst ontleed in functies. Vervolgens werden per functie ideeën gegenereerd.
Tot slot moeten deze ideeën uitgetest worden en vergeleken worden met elkaar.
Het doel van dit onderzoek is om te bepalen welke aandrijfmethode het meest geschikt is om een knop betrouwbaar, gecontroleerd en reproduceerbaar te besturen.
Zie het hoofdstuk Ideeën, voor een overzicht van de bedachte oplossingen.
Dit onderzoek focust uitsluitend op mechanische prestaties en fysieke eigenschappen voor het draaien van knoppen. Er worden geen gebruikersbevragingen of interviews uitgevoerd.

# Werkwijze

Bij het besturen van een draaiknop komen er twee hoofdzaken naar boven:
- Welke actuator zullen we gebruiken?
- Hoe gaan we de draaiknop manipuleren?
Voor beide vragen zullen we hieronder een werkwijze bepalen om tot de beste oplossing te komen.

## Actuator

### 1. Ideeën generatie actuatoren

### 2. De resultaten van vorig onderzoek, die nuttig zijn, worden gebruikt om actuatoren te

elimineren

### 3. Kracht servo apart uittesten op de knop: Een servo is eigenlijk opgebouwd uit een

geborstelde DC motor, met tandwielkast met toevoeging van één of andere sensor. Omdat die feedback van een sensor in deze toepassing belangrijk is, zou het makkelijker zijn, om de servo te gebruiken. Daarvoor moet de servo echter sterk genoeg zijn om de knop te kunnen draaien. Voor die reden wordt de servo nog eens apart uitgetest op de knop.

### 4. Er wordt één finale actuator gekozen

## Manipulatie draaiknop

1. Ideeën generatie om de knop te kunnen manipuleren
2. Er worden prototypes gemaakt voor de verschillende ideeën
3. De prototypes worden uitgetest op de draaiknop van een wasmachine (beiden worden aangestuurd met hetzelfde handvat)
4. De voordelen en nadelen van elk idee worden opgesomd
5. De ideeën worden vergeleken en er wordt één idee uitgekozen

# Ideeën generatie

## Actuatoren

- Servo motor
- Brushed motor
- Brushless motor
- Stepper motor

## Manipulatie van de draaiknop

- Knijper rond draaiknop
- Wieltje die draaiknop doet draaien
- Vertanding op draaiknop met een tandwiel

# Gebruikte artefacten

### Servo opstelling:


De servo werd aangestuurd door een arduino Uno met de voorbeeldcode “sweep”. De servo werd op de knop gemonteerd met dubbelzijdige tape.

### Knijper/klem rond draaiknop



### Wieltje die draaiknop doet draaien



### Vertanding op draaiknop met een tandwiel

Hiervoor werd geen prototype ontwikkeld, door de complexiteit en omdat het principe hard gelijkt op dat van het “Wiel tegen buitenkant draaiknop”.

Zie “1. Draaien van knoppen report” (https://ugentbe-my.sharepoint.com/personal/kylian_maelstaf_ugent_be/Documents/Project%20gebruiksgericht%20ontwerpen/Sustainability%20@%20Home%20-%20Groepswerk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) voor (de bespreking van) de resultaten.

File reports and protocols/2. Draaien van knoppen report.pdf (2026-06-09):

# Draaien van knoppen report

### Sustainability @ Home

Onderzoekers:
Miro Mangelschots - Student Industrieel Ingenieur Industrieel Ontwerpen 2e bachelor Rune Coppieters - Student Industrieel Ingenieur Industrieel Ontwerpen 3e bachelor Kylian Maelstaf - Schakelstudent Industrieel Ingenieur Industrieel Ontwerpen

# Kadering en doelstelling

Dit project richt zich op het automatiseren van “domme” apparaten.
Het product-concept werd eerst ontleed in functies. Vervolgens werden per functie ideeën gegenereerd.
Tot slot moeten deze ideeën uitgetest worden en vergeleken worden met elkaar.
Het doel van dit onderzoek is om te bepalen welke aandrijfmethode het meest geschikt is om een knop betrouwbaar, gecontroleerd en reproduceerbaar te besturen.
Zie het hoofdstuk Ideeën, voor een overzicht van de bedachte oplossingen.
Dit onderzoek focust uitsluitend op mechanische prestaties en fysieke eigenschappen voor het draaien van knoppen. Er worden geen gebruikersbevragingen of interviews uitgevoerd.

# Resultaten

## Vergelijking actuatoren

Hieronder de relevante resultaten uit het voorgaande onderzoek, drukken van knoppen (https://ugentbe-my.sharepoint.com/personal/kylian_maelstaf_ugent_be/Documents/Project%20gebruiksgericht%20ontwerpen/Sustainability%20@%20Home%20-%20Groepswerk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)

De stepper-motor werd niet fysiek uitgetest op de knoppen van de wasmachine.

### Kracht servo test

Servo_draaien
knoppen.mp4
Servo_draaien knoppen.mp4
De servo had niet genoeg kracht om zelfstandig te knop te draaien, maar er was niet veel extra kracht vereist. Er werd niet getest met een sterkere servo-motor, maar er kan vanuit gegaan worden dat grotere servo-motoren wel de knop zouden kunnen draaien.
Kracht | Feedbackloop | Gewicht | Gemak aansturen (extra componenten + code)
Servo | Matig | Ja => hoge precisie + herhaalbaarheid | Matig | Matig
Stepper | Matig | Nee (Maar hoge precisie + herhaalbaarheid, bij geen slip) | Zwaar | Moeilijk
Brushed + geared | Zeer Hoog | Nee | Zwaar | Makkelijk

## Pros & cons manipulatie draaiknop

### Knijper/klem rond draaiknop


Voordeel:
- Er is veel grip door de instelbare klemkracht
- Geen perfect ronde vorm nodig
- Uitstekende vormen zijn geen probleem
- Eenvoudige constructie
Nadeel
- Er is meer kracht nodig dan de andere concepten omdat er geen overbrenging aanwezig is (as motor = as knijper, zonder overbrenging)

### Wieltje die draaiknop doet draaien


Voordelen:
- Door het verschil in diameter tussen het kleine aangedreven wieltje en de draaknop is er een voordelige overbrenging aanwezig die de nodige kracht van de motor verminderd
- Het is een zeer compacte oplossing
- Eenvoudige constructie en montage
Nadelen:
- Weinig grip, waardoor er slip aanwezig is en de draaiknop onbetrouwbaar zal roteren
- Werkt enkel goed met één vorm: een perfect ronde cirkel, zonder uitstekende delen

### Vertanding op draaiknop met een tandwiel

Voordelen:
- Er is een overbrenging aanwezig wat de nodige kracht van de motor verminderd.
- Het is een compacte oplossing
Nadelen:
- Kans op slip tussen tandwielring en draaiknop
- Niet zo universeel
- Werkt enkel goed met één vorm: een perfect ronde cirkel
- Uitstekende delen van de draaiknop zorgen voor problemen
- Verschil in diameter tussen toestellen zorgt voor problemen

# Conclusies

De hoge slip van het klein wiel, tegen de draaiknop, is een groot nadeel van deze oplossing. Tezamen met het nadeel dat enkel perfect ronde draaiknoppen aangestuurd kunnen worden, zorgt ervoor dat deze oplossing uitgesloten wordt.
Ook het tandwiel met tandring heeft het nadeel van ronde draaiknoppen te vereisen… Ook compatibiliteit en slip zijn hier nadelen.
De knijper blijkt dus de beste oplossing te zijn, om de draaiknop aan te sturen.

Uit het vorige onderzoek (drukken van knoppen), kan worden afgeleid dat een geborstelde DC-motor met tandwielkast, de beste oplossing zou zijn. Uit het bijkomend onderzoek is echter gebleken dat Servomotoren ook sterk genoeg kunnen zijn hiervoor, daarbovenop zijn vereisen servomotoren geen toevoeging van een externe sensor, wat dus voor meer simpliciteit zorgt. Voor het draaien van een wasmachine-knop, wordt dus de Servomotor verkozen.

Zie Draaien van knoppen protocol (https://ugentbe-my.sharepoint.com/personal/kylian_maelstaf_ugent_be/Documents/Project%20gebruiksgericht%20ontwerpen/Sustainability%20@%20Home%20-%20Groepswerk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) voor meer detail over de gebruikte methode en artefacten in dit onderzoek.

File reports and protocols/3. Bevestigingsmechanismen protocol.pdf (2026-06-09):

# Bevestegingsmechanismen protocol

### Sustainability @ Home

Onderzoekers:
Miro Mangelschots - Student Industrieel Ingenieur Industrieel Ontwerpen 2e bachelor Rune Coppieters - Student Industrieel Ingenieur Industrieel Ontwerpen 3e bachelor Kylian Maelstaf - Schakelstudent Industrieel Ingenieur Industrieel Ontwerpen

# Kadering en doelstelling

Dit project richt zich op het automatiseren van “domme” apparaten.
Het product-concept werd eerst ontleed in functies. Vervolgens werden per functie ideeën gegenereerd.
Tot slot moeten deze ideeën uitgetest worden en vergeleken worden met elkaar.
Het doel van dit onderzoek is om objectief te bepalen welke bevestigingsmechanismen het meest geschikt zijn om een toestel te monteren op een wasmachine of droogkast.
Zie het hoofdstuk Ideeën, voor een overzicht van de bedachte oplossingen.
Dit onderzoek focust uitsluitend op mechanische prestaties en fysieke eigenschappen voor monteren van een toestel. Er worden geen gebruikersbevragingen of interviews uitgevoerd.

# Ideeën


# Methode

Deel 1: eerste intuïtieve eliminatie.

Deel 2: prototyping + vergelijkend testen.
1. Modulair prototypen
2. Op wasmachine hangen
3. Met weegschaal aan het prototype trekken tot het los komt
4. Filmen bij hoeveel kg kracht het bevestigingsmechanisme lost
5. Maximale kracht opmeten voor trek en moment voor elke oplossing
6. Per oplossing 4 tests uitvoeren: 2x trek & 2x moment
7. Tabel opstellen en gemiddeldes van trek en moment per oplossing berekenen
8. Grafiek opstellen

# Artefacten

Hieronder staan het modulair prototype, de verschillende opzetstukken en het meetinstrument afgebeeld.

## Modulaire hefboom


## Magneet


Om te magneten te bevestigen werden enkele stappen doorlopen, hieronder weergeven:
Stap 1: Magneten in patroon leggen dat overeenkomt met de standaard oppervlakte die gebruikt wordt bij het modulair prototype.

Stap 2: Magneten in een plastic deksel van een pot leggen.

Stap 3: Houten plaat van modulair prototype, in het deksel forceren. De magneten zitten nu opgesloten tussen het deksel en de houten plaat.

## Dubbelzijdige tape


Met beschermingsfilm | Zonder beschermingsfilm

## Gekko tape = Nano tape

## Zuignappen

Om te zuignappen te bevestigen werden enkele stappen doorlopen, hieronder weergeven:

Stap 1: punten aftekenen | Stap 2: Gaten boren


Stap 3: Zuignappen door gaten forseren


## Grote zuignap met hendel


Voor dit prototype werd het handvat van de zuignap met kabelbinders vastgezet op de hefboom.

⬆️ Zuignap met hendel ⬇️Prototype

## Meettoestel: digitale weegschaal

Voor de bespreking van de resultaten en conclusies van dit onderzoek zie Bevestigingsmechanismen report. (https://ugentbe-my.sharepoint.com/personal/kylian_maelstaf_ugent_be/Documents/Project%20gebruiksgericht%20ontwerpen/Sustainability%20@%20Home%20-%20Groepswerk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)

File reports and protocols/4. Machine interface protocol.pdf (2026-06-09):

# Protocol machine interface

Sustainability @ Home
Onderzoekers:
Miro Mangelschots - Student Industrieel Ingenieur Industrieel Ontwerpen 2e bachelor Rune Coppieters - Student Industrieel Ingenieur Industrieel Ontwerpen 3

e bachelor
Kylian Maelstaf - Schakelstudent Industrieel Ingenieur Industrieel Ontwerpen

# Kadering en doelstelling

Dit project is begonnen met het thema duurzaam leven thuis, maar is voor ons geëvolueerd tot het automatiseren van “domme apparaten” na een pivot.
In dit onderzoek willen we ons focussen op hoe deze interactie fysiek uitgevoerd kan worden, specifiek het indrukken van de knoppensequentie.
We willen hiermee de volgende onderzoeksvragen beantwoorden:
- Volgens welk(e) syste(e)m(en) gaan we met ons toestel interageren met andere toestellen?
- Welk systeem is het meest voordelig?

# Werkwijze

We zullen dit trachten te doen door eerst een lijst concepten te bedenken van hoe deze interfacing kan gebeuren, waarna we aan de hand van twee eliminatie methoden tot een “beste” concept komen.
1

## e eliminatie methode

Als eerste eliminatie zullen we een keuzematrix opstellen van alle concepten samen met een aantal criteria, waarbij we elk concept een score zullen geven, en de totalen per concept zullen vergelijken.
2

## e eliminatie methode

Hier zullen we de overblijvende concepten vergelijken en eventueel prototypen, waarna we opnieuw een aantal concepten gaan elimineren. Deze eliminatie zal gebeuren aan de hand van de volgende parameters:
- Transparantie (zichtbaarheid van het interface voor manueel gebruik)
- Grootte van het systeem
- Stabiliteit van het systeem
- Plaatsbaarheid van het systeem op de interface
- Kostprijs van de componenten

# Gebruikte artefacten

## Double rotating arm

Hier word het ontwerp van twee rotatiepunten met op het uiteinde een lineaire beweging eens gemaakt om in de tweede eliminatie te testen.
Voor dit prototype werd gekozen voor zo weinig mogelijk verschillende productietechnieken om een proof of concept te maken. Hierbij werd dus enkel gewerkt met de lasercutter, 3D-printer en bevestigingsmiddelen om dit te realiseren.

### CAD model


### Fysiek model


## Sliding + rotating arm

Hier word het ontwerp van één rotatiepunt en slider met op het uiteinde een lineaire beweging eens gemaakt om in de tweede eliminatie te testen.
Voor dit prototype werd gekozen voor een tandwiel en een getande rand slider in plaats van de schroefdraad slider, zodat het kon gemaakt worden met eenvoudigere productieprocessen. Er werd gewerkt met de lasercutter, 3D-printer en bevestigingsmiddelen om dit te realiseren.

### CAD model


### Fysiek model


## Separate units

Voor de separate units werd een zo klein mogelijke lineaire actuator gemaakt, met de componenten die beschikbaar waren.
De bedoeling was eerst te testen of deze actuator nog sterk genoeg was om de knoppen in te drukken. Vervolgens werd het als referentie gebruikt voor de andere prototypes en als ruwe maat van de separate units.
Hiervoor werd een kleine dc-motor met tandwielkast vastgemaakt aan schroefdraad. Dit geheel werd in een 3D-print omhulsel gestoken, met aan het uiteinde een moer.

Het gaat hier voornamelijk om de diameter van het geheel, niet de lengte.


Voor de bespreking van de resultaten en conclusies van dit onderzoek, zie Machine interface report. (https://ugentbe-my.sharepoint.com/personal/kylian_maelstaf_ugent_be/Documents/Project%20gebruiksgericht%20ontwerpen/Sustainability%20@%20Home%20-%20Groepswerk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)

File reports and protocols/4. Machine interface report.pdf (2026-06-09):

# Protocol machine interface

### Sustainability @ Home

Onderzoekers:
Miro Mangelschots - Student Industrieel Ingenieur Industrieel Ontwerpen 2e bachelor Rune Coppieters - Student Industrieel Ingenieur Industrieel Ontwerpen 3

e bachelor
Kylian Maelstaf - Schakelstudent Industrieel Ingenieur Industrieel Ontwerpen

# Kadering en doelstelling

Dit project is begonnen met het thema duurzaam leven thuis, maar is voor ons geëvolueerd tot het automatiseren van “domme apparaten” na een pivot.
In dit onderzoek willen we ons focussen op hoe deze interactie fysiek uitgevoerd kan worden, specifiek het indrukken van de knoppensequentie.
We willen hiermee de volgende onderzoeksvragen beantwoorden:
- Volgens welk systeem gaan we met ons toestel interageren met andere toestellen?

# Resultaten

1

## e eliminatie - Keuzematrix

Hierin is het gewicht van elke criteria gebaseerd op de voorgaande onderzoeken, namelijk:
- “Interview after pivot” (https://ugentbe-my.sharepoint.com/personal/kylian_maelstaf_ugent_be/Documents/Project%20gebruiksgericht%20ontwerpen/Sustainability%20@%20Home%20-%20Groepswerk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) – Definition fase
- “User interview” (https://ugentbe-my.sharepoint.com/personal/kylian_maelstaf_ugent_be/Documents/Project%20gebruiksgericht%20ontwerpen/Sustainability%20@%20Home%20-%20Groepswerk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) – Discovery fase

Peg board; Grid; Sliding + rotating arm; Rotating pivot arm; Breedte; Diepte; Stabiliteit; Criteria; Gewicht

Nauwkeurigheid | 3 | -1 | -2 | 2 | 2
Complexiteit aansturing | 1 | 2 | 2 | 0 | -2
Setup | 3 | 0 | 0 | 1 | 2
Complexiteit ontwerp | 1 | 2 | 2 | -1 | -1
Universaliteit | 3 | 1 | 1 | 2 | 2
Transparantie | 3 | -2 | -2 | 1 | 2
Totaal | | 4 | 1 | 14 | 21

Lead screw carriage; Rail + slide carriage; Seperate units; Standing carriage; Spider arms

2 | 1 | 2 | -2 | -1
2 | 2 | -1 | 2 | -1
0 | 0 | 2 | 0 | 2
-1 | 0 | 0 | -1 | -1
0 | 1 | 2 | -1 | -2
1 | 1 | 1 | 0 | 1
0 | 1 | 2 | 0 | 0
6 | 10 | 28 | -13 | -12

2

## e eliminatie – Vergelijking componenten & prototypen

### Sliding + rotating arm

- Plaatsbaarheid van het systeem op de interface
- Het enige dat dit systeem nodig heeft van oppervlakte is de basisplaat, die ergens rond de knoppen bevestigd kan worden, uit de weg.


- Transparantie (zichtbaarheid van de interface voor manueel gebruik)
- Hier is op de foto’s te zien dat het systeem kan wegdraaien, waardoor transparantie voor dit concept minder groot is. Het hangt wat af van waar het staat maar meer van de tijd blijft het knoppen bedekken
- Grootte van het systeem
- Hierboven is te zien dat het systeem wel relatief groot is. Ook zou het systeem nog meer afstand laten tussen het wasmachine en de arm want in de rechtse foto paste de knop niet onder de arm.


- Stabiliteit van het systeem
- Hierboven is te zien dat het systeem zeer onstabiel is. Dit is gedeeltelijk te danken aan de afmetingen die de armen moeten hebben en het gewicht van de steppermotor, maar het kan door verdere iteraties verbeterd worden. Bijvoorbeeld:
- Door een wiel aan het uiteinde te bevestigen die vrij kan rondraaien.
- Door een andere servomotor te kiezen die een sterkere verbinding zal vormen.
- Door een lange schroef te pakken die rond draait in de plaats van het tandwiel.
- Door de stepper boven de as van de servo te plaatsen.
- Kostprijs van de componenten
- DC motor met gearbox voor de lineaire actuator: €4 (https://nl.aliexpress.com/item/1005007555396098.html?curPageLogUid=5lH8XXkvfCol)
- SG90 Mini Micro servomotor: €1,76 (https://www.amazon.com/Micro-Helicopter-Airplane-Remote-Controller/dp/B09T3Q7Z6Q)
- 28BYJ-48 Stepper motor: €3,24 (https://www.amazon.com/Reland-Sun-28BYJ-48-ULN2003-Stepper/dp/B09QQK2WXP?xpid=EZJOsfqC5d8G-)
- 3D printen & lasercutten + bevestigingsmiddelen & componenten: ±€10
- Totaal: ±€19

### Double rotating arm

- Plaatsbaarheid van het systeem op de interface
- Het enige dat dit systeem nodig heeft van oppervlakte is de basisplaat, die ergens rond de knoppen bevestigd kan worden, uit de weg.


- Transparantie (zichtbaarheid van het interface voor manueel gebruik)
- Hier is op de foto’s te zien dat het systeem kan samenvouwen, waardoor transparantie voor dit concept geen probleem is.
- Grootte van het systeem
- Hierboven is te zien dat het systeem wel relatief groot is, maar opnieuw door het samenvouwen word dit verminderd.
- Stabiliteit van het systeem
- Hieronder is te zien dat het systeem zeer onstabiel is. Dit is gedeeltelijk te danken aan de afmetingen die de armen moeten hebben, maar het kan door verdere iteraties verbeterd worden. Bijvoorbeeld:
- De rotatie voor het tweede scharnierpunt via een overbrenging laten gebeuren, waardoor de tweede servomotor als tegengewicht gebruikt kan worden.
- Door een andere servomotor te kiezen die een sterkere verbinding zal vormen.
- Door de witte attachment in te werken in de arm, zodat deze stabieler zal worden.


- Kostprijs van de componenten
- DC motor met gearbox voor de lineaire actuator: €4 (https://nl.aliexpress.com/item/1005007555396098.html?curPageLogUid=5lH8XXkvfCol)
- 2x SM-S2309S servomotor: €14 (https://www.amazon.com/SpingRC-SM-S2309S-Micro-analog-plastic/dp/B01CV7CPL6)
- 3D printen & lasercutten + bevestigingsmiddelen & componenten: ±€10
- Totaal: ±€28

### Seperate units

- Transparantie (zichtbaarheid van het interface voor manueel gebruik)
- Dit kan problematisch zijn, aangezien de plaats naast knoppen vaak gebruikt word voor tekstuele communicatie over de functie van de knop.
- Op de gemonteerde plaatsen zijn deze aparte units “permanent” aanwezig
- Grootte van het systeem
- Één unit zal niet groot zijn, maar doordat elke knop een unit nodig heeft zal dit snel de gehele interface veel drukker maken.
- Stabiliteit van het systeem
- Dit zal zeer goed zijn voor deze oplossing.
- Plaatsbaarheid van het systeem op de interface
- Er is bij sommige interfaces niet veel plaats naast de knop om iets te monteren.
- Sommige knoppen staan bovendien dicht bijeen, waardoor twee separate units niet zouden passen


- Kostprijs van de componenten
- Aangezien er per knop op de interface een aparte unit nodig is, gaat de kostprijs snel naar boven, en zal dus veel kostelijker zijn dan de andere oplossingen.

# Conclusies

In de eerste eliminatie hebben we verdergegaan met enkel de gefluorideerde concepten, omdat deze drie concepten het meest uitblinken in de criteria die voor ons project belangrijk is.
Uit de drie geselecteerde componenten was al snel te merken dat de aparte units zouden wegvallen, naast hun vele voordelen in de keuzematrix. Dat komt doordat de hoeveelheid units zeer duur en onhandig zouden worden, aangezien knoppen die dicht bij elkaar staan een probleem zullen worden. Dit zorgt dus voor minder universaliteit dan de andere twee concepten, waardoor deze ook geëlimineerd word.
Zo blijven er enkel nog maar de sliding + rotating arm & de rotating pivot arm over.
Deze twee concepten zullen we elk nog een iteratie geven om de kinderziektes grotendeels weg te werken, waarna we tussen deze nieuwe herwerkte prototypes een keuze zullen maken volgens de gebruiker zijn noden in het volgende onderzoek, zie Gebruikersonderzoek Protocol (https://ugentbe-my.sharepoint.com/personal/kylian_maelstaf_ugent_be/Documents/Project%20gebruiksgericht%20ontwerpen/Sustainability%20@%20Home%20-%20Groepswerk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)

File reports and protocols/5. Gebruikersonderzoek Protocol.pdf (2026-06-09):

# Gebruikersonderzoek Protocol

### Sustainability @ Home

Onderzoekers:
Miro Mangelschots - Student Industrieel Ingenieur Industrieel Ontwerpen 2e bachelor Rune Coppieters - Student Industrieel Ingenieur Industrieel Ontwerpen 3e bachelor Kylian Maelstaf - Schakelstudent Industrieel Ingenieur Industrieel Ontwerpen

# Kadering en doelstelling

Ons project richt zich op het slim maken van “domme” apparaten aan de hand van een knoppendrukker, die automatisch een toestel in- / uitschakelt.
In dit toestel zullen er een aantal zaken bovenkomen die aan de gebruiker gecommuniceerd moeten worden en andersom, die de gebruiker aan het toestel moet communiceren. Hoe deze communicatie het best verloopt word hier tussen twee ontwerpen.
Hiermee zullen we trachten de volgende onderzoeksvragen te beantwoorden:
- Welk ontwerp is gebruiksvriendelijker om in te stellen?
- Welke sequentie ingave is best tijdens de setup?
- Intuïtief om in te stellen?
- Welke obstakels worden er tegengekomen?
- Hoeveel hulp hebben de gebruikers nodig?
- Welk ontwerp / methodiek heeft een te hoge cognitieve belasting? Ook willen we hiermee de volgende usability goals bereiken of verbeteren:
- Intuïtief en gemakkelijk om in te stellen
- Gemakkelijk om te leren hoe het systeem werkt
- Veilig om te gebruiken & in te stellen
- Betrouwbaar in zijn werking

# Methodiek

1. Reeds ondervonden voor- en nadelen per ontwerp met elkaar vergelijken.
2. Wizard of Oz testen volgens deze methodieken, per ontwerp, in de ”app”:
- Arm instellen met sliders
- Arm instellen met joystick
- Foto trekken & punt aanduiden op foto

3. Invullen SUS per methodiek, per ontwerp.
4. Kort interview (QAP) op het einde.

# Werkwijze

## Wizard of Oz testen

### Context

Deze testen zullen uitgevoerd worden op een wasmachine interface.
Hierbij zullen er drie knoppen in sequentie na elkaar ingesteld moeten worden, per methodiek.

### Arm instellen met sliders in app

1. In een app op de gsm word de arm bestuurd met sliders naar de drukplek.
- De onderzoeker beweegt de arm manueel volgens de inputs van de sliders naar de drukplek.
2. Er word een knop ingedrukt in de app om de positie te confirmeren.
3. Een signaal duid aan dat de volgende drukplek ingesteld kan worden.
4. Stappen 1-3 worden herhaald tot alle drie de knoppen ingesteld zijn.

### Arm instellen met joystick in app

1. In een app op de gsm word de arm bestuurd met een joystick naar de drukplek.
- De onderzoeker beweegt de arm manueel volgens de inputs van de joystick naar de drukplek.
2. Er word een knop ingedrukt in de app om de positie te confirmeren.
3. Een signaal duid aan dat de volgende drukplek ingesteld kan worden.
4. Stappen 1-3 worden herhaald tot alle drie de knoppen ingesteld zijn.

### Foto trekken & punt aanduiden op foto in app

1. In een app op de gsm word een foto getrokken van de arm op de interface.
2. De drukplek word op de foto aangeduid.
3. De arm beweegt automatisch naar de drukplek.
- De onderzoeker beweegt de arm manueel naar de drukplek.
4. Er word een knop ingedrukt in de app om de positie te confirmeren.
5. Een signaal duid aan dat de volgende drukplek ingesteld kan worden.
6. Stappen 1-5 worden herhaald tot alle drie de knoppen ingesteld zijn.

## System usability scale (SUS)

De volgende stellingen zullen met een score van 1-5 beoordeeld worden:
- Ik vond de interactie gemakkelijk om uit te voeren.
- Ik vond de bediening intuïtief om te gebruiken.
- Het heeft lang geduurd vooraleer ik begreep hoe het werkte.
- Ik denk dat ik dit zelfstandig zou kunnen instellen zonder ondersteuning.
- Ik moest veel zaken leren vooraleer ik efficiënt met het systeem kon werken.
- Ik zou dit systeem graag regelmatig gebruiken.
- Ik vond dat het systeem veel denkwerk vroeg.
- Ik vond het systeem veilig om te gebruiken.
- Ik vond dat het systeem nauwkeurig mijn bedoelingen kon volgen.
- Ik vond dat het systeem omslachtig was om mee te werken.
Hierbij worden de positieve en negatieve vraagstellingen afgewisseld, om de invloed van de antwoordbias te minimaliseren.

## Interview (QAP)

De volgende vragen zullen tijdens het interview overlopen worden:
- Welke manier van instellen vond u het gemakkelijkst? Waarom?
- Welke manier vond u het moeilijkst om in te stellen? Waarom?
- Waar ondervond u problemen? Leg uit.
- Heeft u ergens (verkeerde) assumpties gemaakt?
- Aanvullende bedenkingen?

# Artefacten

## Sliding + rotating arm

### CAD model


### Fysiek model


## Double pivot arm

Voor dit model te realiseren werd een belt overbrenging gebruikt om het gewicht beter te verdelen en zo de servomotor als tegengewicht te gebruiken.
Voor deze overbrenging werd een teststuk geprint om de optimale as-afstand te vinden.


### CAD model


### Fysiek model


## Web-interface prototype’s

https://peppy-sprinkles-e374be.netlify.app

### Sliders app interface


### Joystick app interface


### Photo + marker


# Metingen

Kwantitatieve metingen
- Tijd om een taak uit te voeren
- Gemiddelde van de drie knop bewegingen
- Tijd gestart vanaf eerste beweging tot de arm in positie is
- Voor de foto methodiek word hier gerekend vanaf de camera gepositioneerd word tot de arm in positie staat
Kwalitatieve metingen
- TAP tijdens de WOz testen
- Welke fouten zijn er gemaakt
- Wat heeft de deelnemer gezegd hierbij
- (Lichaamstaal & houding) Meetinstrumenten
- Filmen van de testen en interviews met geluid
- (Timer)
- (Field notes)

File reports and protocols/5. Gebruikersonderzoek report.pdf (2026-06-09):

# Gebruikersonderzoek Report

### Sustainability @ Home

Onderzoekers:
Miro Mangelschots - Student Industrieel Ingenieur Industrieel Ontwerpen 2e bachelor Rune Coppieters - Student Industrieel Ingenieur Industrieel Ontwerpen 3e bachelor Kylian Maelstaf - Schakelstudent Industrieel Ingenieur Industrieel Ontwerpen

# Kadering en doelstelling

Ons project richt zich op het slim maken van “domme” apparaten aan de hand van een knoppendrukker, die automatisch een toestel in- / uitschakelt.
In dit toestel zullen er een aantal zaken bovenkomen die aan de gebruiker gecommuniceerd moeten worden en andersom, die de gebruiker aan het toestel moet communiceren. Hoe deze communicatie het best verloopt word hier tussen twee ontwerpen.
Hiermee zullen we trachten de volgende onderzoeksvragen te beantwoorden:
- Welk ontwerp is gebruiksvriendelijker om in te stellen?
- Sequentie ingave tijdens de setup?
- Intuïtief om in te stellen?
- Welke obstakels worden er tegengekomen?
- Hoeveel hulp hebben de gebruikers nodig?
- Welk ontwerp / methodiek heeft een te hoge cognitieve belasting? Ook willen we hiermee de volgende usability goals bereiken of verbeteren:
- Intuïtief en gemakkelijk om in te stellen
- Gemakkelijk om te leren hoe het systeem werkt (goede learnability)
- Veilig om te gebruiken & in te stellen
- Betrouwbaar in zijn werking

# Respondenten

Pseudoniem | Relevantie project | Datum | Locatie
Elliot | Eigenaar zonnepanelen & oude wasmachine’s, geen thuisbatterij | 19/05/2026 | Bij Elliot thuis
Eva | Eigenaar
zonnepanelen &
oude wasmachine’s,
geen thuisbatterij
19/05/2026 | Bij Elliot thuis
Julian | Eigenaar
zonnepanelen &
oude wasmachine’s,
geen thuisbatterij
17/05/2026 | Bij Julian thuis
Adrian | Eigenaar
zonnepanelen &
oude wasmachine’s,
geen thuisbatterij
17/05/2026 | Bij Adrian thuis
Rowan | Eigenaar
zonnepanelen &
oude wasmachine’s,
wel een thuisbatterij
02/06/2026 | Bij Rowan thuis

# Resultaten vergelijking voor- en nadelen

### Sliding + rotating arm

Voordelen:
- Stabieler
- Intuïtieve, voorspelbare beweging
Nadelen:
- Lengte is constant, kan niet samenvouwen (minder flexibel)
- Stepper motor is moeilijker om positioneel in te stellen in vergelijking met een servo motor
- Extra circuit board & kabels
- Homing sequentie

### Double rotating arm

Voordelen:
- Kan samenvouwen voor plaatsbesparing
- Minder grote zwaaiende bewegingen nodig tussen de knoppen Nadelen:
- Minder stabiel (2 scharnierpunten die gestabiliseerd moeten worden)
- Complexere aansturing met inverse kinematics
- Bewegingen zijn soms onvoorspelbaar

# Respondent 1 - Elliot

## SUS resultaten




## Antwoorden op eindvragen

Welke manier van instellen vond u het gemakkelijkst? Waarom?
- De beste vorm van instellen was volgens Elliot de foto methode.
- Er is ook een voorkeur hierbij voor de rotating + sliding arm, omdat deze veel intuïtiever beweegt en voorspelbaarder is in zijn bereik en de veiligheidszone.
Welke manier vond u het moeilijkst om in te stellen? Waarom?
- De sliders met de double pivot arm waren de slechtste, aangezien er hiervoor veel denkwerk nodig was om deze correct in te stellen, beide sliders tegelijk besturen vond hij niet intuïtief. Waar ondervond u problemen? Leg uit.
- Bij de foto methode vond hij dat de punt die geplaatst werd op de afbeelding te groot was, je kon moeilijk zonder van dicht een foto te nemen de juiste knop nauwkeurig aanduiden.
- Bij deze methode heeft hij ook meerdere keren proberen inzoomen wat niet mogelijk was. Heeft u ergens (verkeerde) assumpties gemaakt?
- De werking van de joystick was op voor interpretatie
Aanvullende bedenkingen?
- Het instellen van grenzen zou nog een nodige toevoeging zijn volgens hem, zodat je kan instellen waar de zeker arm niet mag komen.
- Ook bijvoorbeeld een knop kunnen instellen dat deze zeker niet ingedrukt kan worden.
- Het bolletje die de knop aanduid bij de foto methodiek was te groot
- Het was onduidelijk welke van de sliders welke motor aanstuurde

## Tijd om een knop in te duwen per methodiek

Sliding + rotating arm – sliders: (24s + 10s + 13s) /3 = 16s
Sliding + rotating arm – joystick: (23s + 9s + 17s) /3 = 16s Sliding + rotating arm – foto: (24s + 21s + 24s) /3 = 23s Double pivot arm – sliders: (23s + 21s + 8s) /3 = 17s Double pivot arm – joystick: (21s + 14s + 11s) /3 = 15s Double pivot arm – foto: (20s + 21s + 26s) /3 = 22s

# Respondent 2 - Eva

## SUS resultaten




## Antwoorden op eindvragen

Welke manier van instellen vond u het gemakkelijkst? Waarom?
- De gemakkelijkste arm om te gebruiken was de sliding + rotating arm
- De gemakkelijkste methodiek was met de camera, dan de joystick, dan de sliders
Welke manier vond u het moeilijkst om in te stellen? Waarom?
- De double pivot arm met de sliders was de moeilijkste, omdat het een moeilijker systeem was om te bedienen en je kon deze ook minder nauwkeurig instellen
Waar ondervond u problemen? Leg uit.
- Eva had geen problemen ondervonden
Heeft u ergens (verkeerde) assumpties gemaakt?
- Welke motor bij welke slider past, en hoe de joystick werkte was wat onduidelijk in de app interface
Aanvullende bedenkingen?
- Ze vind het een nuttig systeem bij oudere systemen, als een extra snufje die erbij gekocht zou worden
- Ze zei dat ze iets van 100 euro zou geven hiervoor aangezien een wasmachine meestal 500 euro kost. Dan is 100 euro erbij als snufje wel goed.

## Tijd om een knop in te duwen per methodiek

Sliding + rotating arm – sliders: (25s + 15s + 28s) /3 = 23s
Sliding + rotating arm – joystick: (19s + 12s + 20s) /3 = 17s Sliding + rotating arm – foto: (22s + 11s + 25s) /3 = 19s Double pivot arm – sliders: (7s + 30s + 12s) /3 = 16s Double pivot arm – joystick: (14s + 5s + 9s) /3 = 9s
Double pivot arm – foto: (12s + 11s + 11s) /3 = 11s

# Respondent 3 - Julian

## SUS resultaten




## Antwoorden op eindvragen

Welke manier van instellen vond u het gemakkelijkst? Waarom?
- De gemakkelijkste arm om te gebruiken was de sliding + rotating arm
- De gemakkelijkste methodiek was met de camera, dan de sliders en als laatste de joystick Welke manier vond u het moeilijkst om in te stellen? Waarom?
- De double pivot arm was de moeilijker, omdat het een moeilijker systeem omdat je altijd weer aanpassingen moest doen en ze elkaar beïnvloeden
- De joystick was het moeilijkst doordat het moeilijk het juiste punt met de joystick aan te duiden
Waar ondervond u problemen? Leg uit.
- Julian heeft geen problemen ondervonden
Heeft u ergens (verkeerde) assumpties gemaakt?
- Ze dacht dat de nano tape ging lossen door de trillingen Aanvullende bedenkingen?
- Ze had niet echt bedenkingen

## Tijd om een knop in te duwen per methodiek

Sliding + rotating arm – sliders: (25s + 22s + 16s) /3 = 21s Sliding + rotating arm – joystick: (17s + 15s + 13s) /3 = 15s Sliding + rotating arm – foto: (25s + 17s + 18s) /3 = 20s Double pivot arm – sliders: (32s + 29s + 20s) /3 = 27s Double pivot arm – joystick: (14s + 5s + 9s) /3 = 14s Double pivot arm – foto: (20s + 10s + 12s) /3 = 16s

# Respondent 4 - Adrian

## SUS resultaten




## Antwoorden op eindvragen

Welke manier van instellen vond u het gemakkelijkst? Waarom?
- De gemakkelijkste arm om te gebruiken was de double pivot arm
- De gemakkelijkste methodiek was met de camera, de tofste methodiek was de sliders Welke manier vond u het moeilijkst om in te stellen? Waarom?
- De joystick was het moeilijkst doordat het moeilijk het juiste punt met de joystick aan te duiden
Waar ondervond u problemen? Leg uit.
- Adrian heeft geen problemen ondervonden
Heeft u ergens (verkeerde) assumpties gemaakt?
- Hij had twijfels over de nano tape Aanvullende bedenkingen?
- Hij had niet echt bedenkingen

## Tijd om een knop in te duwen per methodiek

- Note: Adrian deed het trager zodat de onderzoeker makkelijker kon volgen Sliding + rotating arm – sliders: (34s + 31s + 30s) /3 = 32s
Sliding + rotating arm – joystick: (18s + 13s + 14s) /3 = 15s
Sliding + rotating arm – foto: (21s + 20s + 19s) /3 = 20s
Double pivot arm – sliders: (35s + 34s + 32s) /3 = 34s Double pivot arm – joystick: (18s + 12s + 13s) /3 = 14s Double pivot arm – foto: (26s + 25s + 25s) /3 = 25s

# Respondent 5 - Rowan

## SUS resultaten




## Antwoorden op eindvragen

Welke manier van instellen vond u het gemakkelijkst? Waarom?
- De rotating + sliding arm met de joystick vond hij het gemakkelijkste, omdat je de arm kan roteren, zodat de arm uitgelijnd staat met de knop, en dan was het nog enkel maar de drukker zelf naar de knop brengen.
Welke manier vond u het moeilijkst om in te stellen? Waarom?
- De double pivot arm met de sliders / joystick vond hij de moeilijkste, omdat het moeilijk inschatten was waar de arm zou uitkomen.
Waar ondervond u problemen? Leg uit.
- Er was backlash bij de double pivot arm, wat het instellen moeilijk maakte, ook dat de arm soms te snel bewoog wat het moeilijk maakte om in te schatten.
Heeft u ergens (verkeerde) assumpties gemaakt?
- Rowan had geen opmerkingen hierbij.
Aanvullende bedenkingen?
- Hij zei nogmaals dat de arm wat trager zou moeten bewegen maar ook dat de bekabeling mooi ingewerkt zou moeten worden om het systeem bruikbaarder te maken.

## Tijd om een knop in te duwen per methodiek

Sliding + rotating arm – sliders: (30s + 17s + 20s) /3 = 22s
Sliding + rotating arm – joystick: (17s + 6s + 10s) /3 = 11s Sliding + rotating arm – foto: (33s + 25s + 18s) /3 = 25s Double pivot arm – sliders: (59s + 25s + 23s) /3 = 36s Double pivot arm – joystick: (8s + 9s + 7s) /3 = 8s Double pivot arm – foto: (24s + 20s + 27s) /3 = 24s

# Concluderende data

## SUS analyse

SR: sliding + rotating arm; RR: double pivot arm; SR-sliders; SR-joystick; SR-foto; RR-sliders; RR-joystick; RR-foto; Score op 5; Gemiddelde scores
Gemiddelde scores; SR-sliders; SR-joystick; SR-foto; RR-sliders; RR-joystick; RR-foto

- Bij negatieve vragen werd de score omgedraaid.

## Tijd analyse per methodiek per arm

SR-sliders; SR-joystick; SR-foto; RR-sliders; RR-joystick; RR-foto; Tijd in seconden; Gemiddelde tijden

- Note 1: Bij de foto methodes is er enkel maar input van de respondent tot de confirm knop geduwd word. Hier is een studie van tijd dus niet echt van toepassing aangezien de focus hier op de arm ligt.
- Hier werd gerekend vanaf de camera gericht begon te worden tot de robot op de juiste plaats stond.
- Note 2: Bij de sliding + rotating arm is de sliding beweging zeer traag, wat deze tijden veel hoger laat uitkomen dan ze normaal zouden zijn.
- Note 3: Vaak is het dat de arm al op een goede positie staat en de volgende knop onder de 10s bereikt word, wat deze tijden veel lager laat uitkomen.

## Eindvragen

Hieruit kan er een duidelijke voorkeur voor de sliding + rotating arm afgelezen worden, omdat de beweging intuïtiever en voorspelbaarder is, doordat de rotatie eigenlijk al direct je arm in de juiste positie zet die je nodig hebt, zonder constant te moeten bijstellen tussen twee scharnierpunten.
De cameramethode was door velen de gemakkelijkste om te gebruiken en sliders waren in het algemeen veel moeilijker te gebruiken.

# Finale conclusies

Doorheen de drie toegepaste methodes die we gebruikt hebben was zeer duidelijk te zien dat de double pivot arm veel nadelen had:
- Niet intuïtief om handmatig te bewegen met de sliders
- Onvoorspelbare bewegingen
- Vraagt complexe berekeningen met inverse kinematics indien de slider / foto methode gebruikt word.
Daarentegen heeft de sliding + rotating arm veel voordelen:
- Makkelijkere constructie, naast de homing sequentie van de stepper motor
- Intuïtieve beweging
- Simpelere berekeningen
Aangezien de double pivot arm voor elke methode doorslaggevende nadelen heeft, zal deze arm niet gekozen worden.
Dan resteert ons enkel nog de sliding + rotating arm, waarbij de foto methodiek voor de gebruiker de beste optie is.
Indien er manuele besturing nodig is, is te zien dat de joystick de beste optie is.
Hierin zou de app nog wat meer begeleiding kunnen geven in beide interfaces van foto en joystick en het bolletje die de knop aanduid op de foto methodiek zou kleiner moeten worden.

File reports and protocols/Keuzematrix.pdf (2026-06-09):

Schet s | Naam | Breedt e | Diept e | Stabilite it | Nauwkeurigh eid | Complexiti et Aansturing | Setu p | Hoeveelhe id Actuatore n | Ontwerp complexiti et | Universalit eit | transparant ie
| Peg Board | -2 | 2 | 2 | -1 | 2 | 0 | #knoppen | 2 | 1 | -2
| Grid | -2 | 2 | 2 | -2 | 2 | 0 | #knoppen | 2 | 1 | -2
| Sliding+ Rotating arm | -1 | 1 | -1 | 2 | 0 | 1 | 3 | -1 | 2 | 1
| Rotating pivot arm | 1 | 1 | -2 | 2 | -2 | 2 | 3 | -1 | 2 | 2
| Lead screw or belt carriage | -2 | 0 | 2 | 2 | 0 | -1 | 4 | 0 | 1 | 0
| Rail+ slide carriage | -2 | 0 | 1 | 2 | 0 | 0 | 3 | 1 | 1 | 1
| Separate units | 2 | 2 | 2 | -1 | 2 | 0 | #knoppen | 2 | 1 | 2
| Standing Carriage | -1 | -2 | -2 | 2 | 0 | -1 | 2 | -1 | 0 | 0
| Spider arms (klembaa r) | -1 | -1 | -1 | -1 | 2 | -1 | #knoppen | -2 | 1 | 0

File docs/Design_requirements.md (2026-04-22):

<!--### Groep 1 – De centrale hub
| :x: = Niet voldaan | :warning: = Niet volledig voldaan | :white_check_mark: = Voldaan |
| ID | Design Requirement | Source | Date ||
|----|--------------------|--------|------|--|
| 1.1 | De centrale hub laat gebruikers toe hun energieverbruik te bekijken in euro’s. | User interview | 26/10/2025 |:x:|
| 1.2 | De centrale hub laat gebruikers toe hun energieverbruik te bekijken, uitgedrukt in watt. | Usability research interface hub | 23/11/2025 |:x:|
| 1.3 | De centrale hub kan energieverbruik weergeven per dag, week, maand en jaar. | Usability research interface hub | 23/11/2025 |:x:|
| 1.4 | De centrale hub toont gemiddelde energieverbruiken. | Usability research interface hub | 23/11/2025 |:x:|
| 1.5 | De centrale hub toont het totale energieverbruik. | Usability research interface hub | 23/11/2025 |:x:|
| 1.6 | De centrale hub laat toe weekdagen en weekenddagen apart in te stellen. | Usability research interface hub | 23/11/2025 |:x:|
| 1.7 | De centrale hub kan toestellen activeren en deactiveren. | User interview | 26/10/2025 |:x:|
| 1.7.1 | De centrale hub kan communiceren met de knoppencontroller. | Functie-analyse | 04/01/2026 |:x:|
| 1.7.2 | De centrale hub kan communiceren met slimme stekkers. | Functie-analyse | 04/01/2026 |:x:|
| 1.8 | De centrale hub kan de optimale timing bepalen om toestellen aan te sturen. | Functie-analyse | 04/01/2026 |:x:|
| 1.9 | De centrale hub kan de output van zonnepanelen uitlezen. | Functie-analyse | 04/01/2026 |:x:|
| 1.10 | De centrale hub kan meten hoeveel energie elk apparaat verbruikt. | Functie-analyse | 04/01/2026 |:x:|
| 1.11 | De centrale hub kan de actuele energieprijs koppelen aan het verbruik. | User interview | 26/10/2025 |:x:|
| 1.12 | De centrale hub ondersteunt het instellen van prioriteiten, voor het aansturen van toestellen. | Functie-analyse | 04/01/2026 |:x:|
| 1.13 | De centrale hub ondersteunt tijdslimieten voor energieverbruik per toestel. | User interview | 26/10/2025 |:x:|
| 1.14 | De centrale hub is gebruiksvriendelijk en intuïtief te navigeren. | Usability research interface hub | 23/11/2025 |:x:|
| 1.15 | De centrale hub is voldoende leesbaar in verschillende omgevingen. | Usability research interface hub | 23/11/2025 |:x:|
| 1.16 | De centrale hub is energie-efficiënt. | User interview | 26/10/2025 |:x:|
| 1.17 | De centrale hub kan op meerdere manieren geplaatst worden in een ruimte. | User interview | 26/10/2025 |:x:|
| 1.17.1 | De centrale hub is monteerbaar aan een muur. | User interview | 26/10/2025 |:x:|
| 1.17.2 | De centrale hub kan rechtopstaand op een tafel geplaatst worden. | User interview | 26/10/2025 |:x:|
| 1.17.3 | De centrale hub kan comfortabel in de hand genomen worden door de gebruiker. | User interview | 26/10/2025 |:x:|
| 1.18 | De centrale hub heeft een esthetisch en modern ontwerp. | User interview | 26/10/2025 |:x:|
| 1.19 | De centrale hub kan door de gebruiker zelf gemonteerd worden. | User interview | 26/10/2025 |:x:|-->
## Design requirements

### Groep 1 – Knoppencontroller
| :x: = Niet voldaan | :warning: = Niet volledig voldaan | :white_check_mark: = Voldaan |
| ID | Design Requirement | Source | Date ||
|----|--------------------|--------|------|--|
| 3.1 | De knoppencontroller kan gebruikt worden om interfaces te bedienen. | Usability research interface hub | 23/11/2025 |:x:|
| 3.1.1 | De knoppencontroller kan knoppen in drukken. | User interview | 26/10/2025 |:x:|
| 3.1.2 | De knoppencontroller kan knoppen draaien. | User interview | 26/10/2025 |:x:|
| 3.1.3 | De knoppencontroller kan touchscreens bedienen. | User interview | 26/10/2025 |:x:|
| 3.2 | De knoppencontroller is universeel monteerbaar. | User interview | 26/10/2025 |:x:|
| 3.2.1 | De knoppencontroller kan op verschillende oppervlakken bevestigd worden. | User interview | 26/10/2025 |:x:|
| 3.2.2 | De knoppencontroller kan op verschillende manieren bevestigd worden. | User interview | 26/10/2025 |:x:|
| 3.3 | De knoppencontroller heeft een esthetisch ontwerp. | User interview | 26/10/2025 |:x:|
| 3.4 | De knoppencontroller is robuust en geschikt voor dagelijks gebruik. | User interview | 26/10/2025 |:x:|
| 3.5 | De knoppencontroller kan door de gebruiker zelf gemonteerd worden. | User interview | 26/10/2025 |:x:|
| 3.6 |De knoppencontroller kan specifieke programma’s uitvoeren | interview after pivot | 11/03/2026 |:x:|
| 3.7 | De knoppencontroller is betrouwbaar | interview after pivot | 11/03/2026 |:x:|
| 3.8 | De knoppencontroller is herbruikbaar | interview after pivot | 11/03/2026 |:x:|
| 3.9 | De knoppencontroller is makkelijk te integreren, zonder demontage | interview after pivot | 11/03/2026 |:x:|
| 3.10 | De knoppencontroller kan ingesteld worden in minder dan vijf minuten | interview after pivot | 11/03/2026 |:x:|
| 3.11 | De knoppencontroller kan zijn waarde terugverdienen binnen de 3 jaar | interview after pivot | 11/03/2026 |:x:|
| 3.12 | De knoppencontroller kan zelfstandig werken | interview after pivot | 11/03/2026 |:x:|

### Groep 2 – Slimme stekkers (plug & play)
| :x: = Niet voldaan | :warning: = Niet volledig voldaan | :white_check_mark: = Voldaan |
| ID | Design Requirement | Source | Date ||
|----|--------------------|--------|------|--|
| 2.1 | Slimme stekkers kunnen communiceren met de centrale hub. | Functie-analyse | 04/01/2026 |:x:|
| 2.2 | Slimme stekkers kunnen de stroomtoevoer naar een toestel onderbreken of toelaten. | Functie-analyse | 04/01/2026 |:white_check_mark:|
| 2.3 | Slimme stekkers kunnen het energieverbruik van een aangesloten toestel meten. | Functie-analyse | 04/01/2026 |:white_check_mark:|
| 2.4 | Slimme stekkers zijn energie-efficiënt tijdens gebruik. | User interview | 26/10/2025 |:white_check_mark:|
| 2.5 | Slimme stekkers kunnen door de gebruiker zelf geïnstalleerd worden. | User interview | 26/10/2025 |:white_check_mark:|

<br>

---

<p align="center">
  <a href="/Design_requirements.md">⬆️ Return to top</a><br>
  <a href="/README.md">🏠 Return to main<a><br>
  <a href="/LICENSE">📜 CC License</a> & <a href="/LICENSE">MIT License</a><br>

</p>

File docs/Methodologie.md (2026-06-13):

## Methodologie

Als methodologie wordt een aangepaste versie van het "dubble diamont" model gebruikt, namelijk het "tripple diamont model":



Beide ontwerpmodellen zijn gebaseerd op twee terugkerende principes: divergentie en convergentie. 

Bij divergentie worden opties gecreëerd.

Bij convergentie worden er keuzes gemaakt tussen deze opties.

Elke fase van het model bestaat uit deze twee principes, maar divergentie-convergentie wordt ook op kleinere schaal toegepast. Dit wordt voorgesteld door de kleinere ruiten in de grotere ruiten, die de fasen voorstellen.

Het "triple diamond"-model bestaat uit meerdere fasen, die hieronder kort worden uitgelegd:

### Discover
Deze fase speelt zich af in de probleemruimte. De bedoeling is volop op zoek te gaan naar problemen en opportuniteiten.

In deze fase werd eerst onderzoek gedaan naar een probleem; vervolgens werd onderzocht of dit een goede opportuniteit was.

Deze fase wordt ook in detail besproken in [Discovery](1_Discovery.md)

### Define
De define-fase speelt zich af in de oplossingsruimte Hier is de bedoeling om oplossingen te zoeken voor het probleem dat uit de discover-fase is gekomen.

Bij deze fase bleek het een uitdaging te zijn om ons op het juiste pad te houden en niet de mist in te wandelen...

Er werd eerst onderzoek gedaan naar de meest intuïtieve layout van een scherminterface Dit onderzoek had bij nader inzien beter gepast bij de develop-fase.

Na dit onderzoek werd beseft dat we niet eens wisten aan welke functies dat "intuïtieve interface" moest voldoen. Het volgende onderzoek was dus in verband met de functies van het apparaat.

Deze fase wordt in meer detail besproken in [Definition](2_Definition.md)

### Develop
De develop-fase bouwt verder op de inzichten uit de define-fase en focust op het concreet uitwerken en testen van oplossingen. Deze fase wordt opgedeeld in drie stappen: Develop 1, Develop 2 en Develop 3.

In **Develop 1** werd inzicht verworven in de gebruikers en de technische werking. Via user interviews en fysieke tests werd bepaald welke actuatoren geschikt zijn en welke eisen gebruikers stellen aan het product, zoals betrouwbaarheid, gebruiksgemak en snelle setup.

Deze fase wordt in meer detail besproken in [Develop 1](3_Develop_1.md)

In **Develop 2** werden verschillende deeloplossingen verder uitgewerkt en vergeleken. Door middel van prototyping, keuzematrices en gebruikerstesten werd er een selectie gemaakt voor de beste mechanismen, zoals de sliding + rotating arm, geschikte actuatoren en bevestigingsmethodes. 

Deze fase wordt in meer detail besproken in [Develop 2](4_Develop_2.md)

In **Develop 3** lag de focus op vormgeving, materiaalkeuze en gebruikerservaring (CMF + UX). Verschillende varianten werden ontwikkeld en getest om te bepalen welke het meeste vertrouwen, duurzaamheid en gebruiksvriendelijkheid uitstralen. 

Deze fase wordt in meer detail besproken in [Develop 3](5_Develop_3.md)

Doorheen deze fase werd continu gedivergeerd en geconvergeerd, waarbij ideeën werden gegenereerd, getest en vervolgens gefilterd tot een onderbouwde ontwerpkeuze.

### Deliver

Het doel van het Minimum Viable Product (MVP) was om de meest essentiële interacties van het concept te demonstreren en te valideren.

Voor het [MVP](../docs/MVP.md) werden volgende vereisten opgesteld:

- Meerdere knoppen moeten kunnen worden ingedrukt.
- Minstens één draaiknop moet kunnen worden bediend.
- Het apparaat moet stevig bevestigd kunnen worden op een wasmachine.

Tijdens de ontwikkeling zijn de eerste en derde vereiste succesvol gerealiseerd. Het prototype kan meerdere knoppen bedienen en kan op een wasmachine worden bevestigd zoals voorzien.

De bediening van een draaiknop kon echter niet volledig worden geïmplementeerd binnen de beschikbare projecttijd. Hoewel hiervoor concepten en technische oplossingen werden onderzocht, werd deze functionaliteit niet opgenomen in het finale prototype. Dit vormt een belangrijk aandachtspunt voor toekomstige iteraties van het ontwerp.

Ondanks deze beperking slaagt het MVP erin de kern van het concept aan te tonen en de belangrijkste interacties te valideren. Het prototype levert waardevolle inzichten op voor een verdere ontwikkeling richting een volledig functioneel product.

<br>

---

<p align="center">
  <a href="/Methodologie.md">⬆️ Return to top</a><br>
  <a href="/README.md">🏠 Return to main<a><br>
  <a href="/LICENSE">📜 CC License</a> & <a href="/LICENSE">MIT License</a><br>

</p>

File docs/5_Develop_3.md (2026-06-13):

## Develop 3

### Doelstellingen  

In Develop 2 werden de functionele en technische deeloplossingen geselecteerd.  
In Develop 3 wordt de focus gelegd op de vormgeving, materialen en gebruikersbeleving van het product (CMF + UX).  

Er wordt onderzocht:  
- Hoe het product eruit moet zien  
- Welke materialen en afwerkingen het meest geschikt zijn  
- Hoe het product wordt ervaren door de gebruiker  

<br>

### Methoden  

#### 1. Bepalen van gewenste ervaring  

- Analyse van gewenste emoties (vertrouwen, betrouwbaarheid, duurzaamheid)  
- Benchmark van gelijkaardige bedrijven (o.a. Apple, Braun, Philips, Nothing, …)  
- Vertalen van deze inzichten naar kernwoorden voor vorm, materiaal, kleur en afwerking  

<br>

#### 2. CMF exploratie  

1. Kernwoorden bepalen voor:  
   - Vorm (geometrisch, symmetrisch, afgerond, monolithisch)  
   - Kleur (neutraal, monochroom, accenten voor functies)  
   - Materiaal (robuust, massief, slijtvast)  
   - Afwerking (mat, tactiel, smooth)  

2. Opstellen van een morfologische matrix met verschillende CMF varianten  

3. Genereren van varianten op basis van V3 prototype  

<br>

#### 3. Iteratie & visualisatie  

- Genereren van visuele varianten (Vizcom)  
- Toepassen van kleur-, materiaal- en afwerkingscombinaties  
- Uitwerken van meerdere CMF richtingen  

<br>

### CMF Varianten  

- Variant 1  
   Bead blasted aluminium
<p align="left">
  
</p>

-  Variant 2  
   Matte polycarbonaat
<p align="left">
  
</p>

- Variant 3  
  Ultra matte ABS
<p align="left">
  
</p>

- Variant 4  
  Matte nylon
<p align="left">
  
</p>

- Variant 5  
  Low-gloss satin PET-G met transparante accenten
<p align="left">
  
</p>

<br>

#### 4. Gebruikersonderzoek  
De verschillende CMF varianten worden geëvalueerd via gebruikerstesten:  

- Vergelijking van visuele varianten  
- Beoordeling van materialen en texturen (ook blind)  
- Interviews (QAP) rond voorkeur, vertrouwen en gebruik  

Onderzoeksvragen:  
- Welke variant straalt het meeste vertrouwen uit?  
- Welke materialen lijken het meest duurzaam en onderhoudsvriendelijk?  
- Welke vormgeving past het best binnen de context van een wasmachine?  

<br>

### Resultaten  
#### 1.Benchmarkanalyse
<p align="left">
  
  
- **Functie & omgeving**  
  - Het product wordt gebruikt op wasmachines en droogkasten, vaak in een vochtige omgeving  
  - Ontwerpkeuzes moeten daarom waterbestendigheid, onderhoudsgemak en betrouwbaarheid ondersteunen  
  - Eenvoudig reinigbare oppervlakken en gesloten vormen zijn cruciaal om vuilophoping te vermijden  

- **Gelijkaardige producten & bedrijven**  
  - Analyse van bedrijven zoals Apple, Braun, Philips, Nothing en Switchbot toont een duidelijke focus op minimalisme, precisie en gebruiksvriendelijkheid  
  - Deze producten combineren eenvoudige geometrieën met hoogwaardige materialen om vertrouwen en kwaliteit uit te stralen  
  - Een consistente, rustige vormtaal blijkt essentieel om technologie toegankelijk en betrouwbaar te laten aanvoelen  

- **Vorm**  
  - Geometrische en symmetrische vormen worden geassocieerd met controle en betrouwbaarheid  
  - Monolithische en gesloten volumes versterken de perceptie van waterbestendigheid en onderhoudsgemak  
  - Afgeronde randen verhogen de perceptie van veiligheid en gebruiksvriendelijkheid  
  - Proportionele en visueel evenwichtige ontwerpen versterken de perceptie van robuustheid, stabiliteit en vertrouwen  

- **Emotie**  
  - Tijdloze vormgeving wordt geassocieerd met duurzaamheid en langdurige relevantie  
  - Neutrale, discrete en sobere ontwerpen zorgen voor een rustige uitstraling en integreren beter in de omgeving  
  - Een terughoudende vormentaal versterkt het gevoel van kwaliteit en betrouwbaarheid  

- **Kleur**  
  - Neutrale en monochrome kleurpaletten zorgen voor visuele rust en integratie in de omgeving  
  - Monochromatic kleurgebruik versterkt het gevoel van coherentie en vertrouwen  
  - Subtiele accenten helpen bij het communiceren van functies zonder visuele druk  

- **Materiaal**  
  - Robuuste en massieve materialen worden gepercipieerd als duurzamer en betrouwbaarder  
  - Slijtvastheid en weerbestendigheid verhogen het vertrouwen in langdurig gebruik  

- **Afwerking**  
  - Matte en low-gloss oppervlakken verhogen de perceptie van cleanliness en laten het product duurzamer lijken  
  - Deze afwerkingen verminderen zichtbare gebruikssporen en vingerafdrukken  
  - Tactiele en gladde afwerkingen verbeteren de gebruikerservaring en onderhoudsvriendelijkheid  

<br>

#### 2. Gebruikersonderzoek CMF  

De verschillende CMF varianten werden geëvalueerd via interviews (N = 5), waarbij voorkeur, perceptie van kwaliteit en geschiktheid binnen de context van een wasmachine werden onderzocht.  

De resultaten tonen duidelijke trends in hoe de varianten worden ervaren:  

- **Voorkeur & perceptie**  
  - Variant 1 wordt het meest gekozen als voorkeursoptie  
  - Aluminium wordt sterk geassocieerd met kwaliteit, stevigheid en betrouwbaarheid  
  - Varianten 3 en 4 worden gewaardeerd om hun neutrale en sobere uitstraling  

- **Negatieve perceptie**  
  - Variant 5 wordt consistent negatief beoordeeld door het gebruik van meerdere kleuren en een chaotische uitstraling  
  - Variant 2 wordt gezien als goedkoop en fragiel, wat het vertrouwen in het product verlaagt  

- **Materiaalperceptie**  
  - Aluminium wordt door de meeste gebruikers gezien als het meest duurzame en kwalitatieve materiaal  
  - ABS wordt ook positief beoordeeld als alternatief materiaal  
  - Plastiek in transparante of lichte varianten wordt sneller als minder stevig ervaren  

- **Kleur & esthetiek**  
  - Neutrale kleuren worden als rustgevend en passend ervaren binnen de context van huishoudtoestellen  
  - Felle of contrasterende combinaties worden als storend en minder professioneel ervaren  
  - Monochrome grijstinten worden geassocieerd met duurzaamheid en tijdloosheid  

- **Onderhoud & duurzaamheid**  
  - Aluminium en matte afwerkingen worden als onderhoudsvriendelijk en duurzaam ervaren  
  - Vingerafdrukken en verkleuring worden als mogelijke nadelen gezien bij bepaalde plastieken  

- **Professionele uitstraling**  
  - Variant 1 scoort het hoogst op professionele uitstraling  
  - Varianten 3 en 4 volgen als neutrale en veilige keuzes  
  - Varianten 2 en 5 worden als minst professioneel ervaren  

### Conclusies & implicaties  

- Variant 1 is de beste oplossing, omwille van zijn sterke perceptie van kwaliteit, robuustheid en betrouwbaarheid bij gebruikers.  

- Aluminium wordt gezien als het meest geschikte materiaal, met ABS als valabel alternatief door zijn goede balans tussen duurzaamheid en maakbaarheid.  

### Finaal ontwerp
<p align="left">
  
</p>
<br><br>
 Voor meer detail over dit onderzoek, zie <a href="../reports and protocols/6.CMF_protocol.pdf">CMF protocol</a>, <a href="../reports and protocols/6.CMF_report.pdf">CMF report</a>.
</p>
<br>
<p align="center">
  <a href="/5_Develop_3.md">⬆️ Return to top</a><br>
  <a href="/README.md">🏠 Return to main<a><br>
  <a href="/LICENSE">📜 CC License</a> & <a href="/LICENSE">MIT License</a><br>

</p>

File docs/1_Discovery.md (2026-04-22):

## Discovery

### Doelstellingen

Het doel van deze fase in het ontwerpproces is om een eerste oriëntatie van de probleemruimte te voltooien en te onderzoeken voor welke onderverdelingen van duurzaamheid, in de thuiscontext, er al oplossingen bestaan. Het doel is om daarna een probleem te kiezen en uit te zoeken, of dit een reëel probleem is. Het is ook de bedoeling om een eerste onderzoek te doen, naar de wensen en noden van gebruikers.

### Methoden

Het is een uitdaging om vanuit een brede term, zoals "duurzaamheid in huis", terecht te komen bij een specifiek probleem. Om deze stap makkelijker en meer gestructureerd te laten verlopen, werd eerst de term "duurzaamheid" ontleed in de drie domeinen van duurzaamheid (3P) namelijk: "People", "Planet", "Profit". Vervolgens werden deze domeinen ontleed in categorieën, die op hun beurt werden opgesplitst in specifieke onderwerpen. Voor elk van deze onderwerpen werden problemen bedacht, om tot een hele lijst problemen, binnen het thema te komen.
<p align="center">
  
</p>

Om te helpen bij het opstellen van deze probleem-lijst, werd parallel een benchmark opgesteld, die ook van grote hulp was bij het kiezen van een finaal probleem. Deze benchmark werd afgelegd aan de hand van online beschikbare informatie. Voor meer informatie omtrent de benchmark zie <a href="../reports and protocols/S@H_Benchmark protocol.pdf">Benchmark protocol</a>. Het resultaat van deze benchmark staat onder [Resultaten - Benchmark](#benchmark-N10), verder op deze pagina of in het [Benchmark report](../reports%20and%20protocols/S@H_Benchmark%20report.pdf).

Uit deze lijst met problemen werden de meest aantrekkelijke exemplaren geselecteerd. Op de problemen in deze selectie, werd wat dieper nagedacht, waarna deze tegenover elkaar werden vergeleken. Ook werd rekening gehouden met de benchmark. Vervolgens werd op wijze van eliminatie, een finale uitdaging gekozen.

<p align="center">
  
</p>

Het geselecteerde probleem is: Door variërende energieprijzen, betalen gebruikers meer voor hun energie, dan nodig is. Als doelgroep werden gezinnen, met drie of meer gezinsleden, gekozen.

Vervolgens werd een User interview uitgevoerd, met deze doelgroep, om uit te zoeken of het geselecteerde probleem een realistisch probleem is en wat de wensen en noden zijn van de gebruikers. In dit user interview werd ook een habit analysis uitgevoerd. Diepgaande uitleg over dit onderzoek vindt u in het [User interview protocol](../reports%20and%20protocols/S@H_User%20Interview%20Protocol.pdf). De resultaten van de interviews en de habit analysis worden kort besproken bij [Resultaten - User interview](#user-interview-N3) en [Resultaten - Habit analysis](#habit-analysis-N3). Voor een gedetailleerde analyse hiervan zie [User interview report](../reports%20and%20protocols/S@H_User%20interview%20report.pdf)

</br>

### Resultaten

#### Benchmark (N=10)
Hieronder staat de resulterende benchmark afgebeeld:
<p align="center">
  
</p>
De resultaten van de benchmark worden kort besproken.
Volgende oplossingen bestaan al in overvloed:

- warmte regelende toestellen (slimme thermostaten)
- slimme energiemeters
- apparaat om watergebruik te regelen

Om energieverbruik tastbaar te maken voor kinderen, bestaan bijna geen oplossingen.
Om gebruik te maken van daluur-energieprijzen, bestaan er thuisbatterijen, deze zijn echter gigantisch duur.
Theoretisch gezien, is het aan/uit schakelen van apparaten met slimme stekkers, ook een optie. Het probleem daarbij is dat er nog geen ready-made oplossing bestaat voor “het brein” van een zo een systeem. Bovendien is dit maar compatibel met enkele apparaten: Apparaten als wasmachines, vaatwassers en droogkasten hebben meer input nodig dan enkel de stekker insteken.

De probleemstellingen, waar verder kan op ingegaan worden, zijn dus:
-	Energieverbruik ongrijpbaar voor kinderen
-	Piekverbruik / varierende energieprijs

</br>

#### Habit analysis (N=3)

Dit zijn de resultaten van de habit analysis:
<p align="center">
  
</p>
<p align="left">
  
</p>
<p align="center">
  
</p>
</br>

#### User interview (N=3)

Alle drie de respondenten hadden "toevallig" zonnepanelen. Ze hadden daarbij maar een kleine of zelfs geen batterij, daardoor bleek het moeilijk om energieverbruik af te stellen op de productie van de zonnepanelen.
Langst de andere kant, had geen enkele respondent een dynamisch energietarief.

De meeste gebruikers werken overdag, waardoor ze er niet mee bezig kunnen zijn. Bovendien hebben ze daar ook geen tijd of zin voor.

>“Je moet er zo hard mee bezig zijn, da je der op den duur geen zin meer in hebt.”

Wat ook terugkwam bij alle interviews, is dat de respondenten niet echt kijken naar hun energiefactuur. Ze geven aan dat ze geen stress ondervinden, maar het eerder zien als kansen waar ze geen gebruik van kunnen maken.

Ook vonden de gebruikers energieverbruik zeer moeilijk vatbaar, omdat ze geen referentiepunt hebben en niet gekend zijn met wattage. Ze hadden dus een voorkeur voor het verbruik in euro weer te geven, omdat ze dat beter begrijpen.

>“Als ge ziet ik heb 10 MW bespaart of ik heb 10euro bespaart, het een zegt meer, als het andere.”

>“Ik vind dat energieverbruik iets heel abstract” “Als iemand da mij niet uitlegt, heb ik daar echt geen flauw idee van”

##### Product voorkeuren:
**Automatisch:**
De gebruikers hadden het systeem liefst zo automatisch mogelijk, zodat ze er niet over moeten nadenken of mee bezig zijn.

Bij het automatisch schakelen van apparaten werd voorgesteld om dat op basis van de energie van de zonnepanelen te doen en om de voorrang van apparaten in te kunnen stellen.

>“Als er echt veel zon is, dan mag eerst pomp 1 laten draaien, als er nog over is, pomp 2, dan warm
water…”

**Interface:**
De respondenten hadden de voorkeur voor een fysiek scherm, over een app, alhoewel een app ook handig zou zijn. 
Eén respondent zei dat hij een fysiek scherm makkelijk zou vinden, maar dat dat in de praktijk, problemen met zich meebrengt, zoals installatiekosten, een "lelijk apparaat" dat ophangt in je huis en dat een fysiek scherm meer zou kosten dan een app... 

Wat de gebruikers zelf ook aangaven, is dat ze graag hun totaalverbruik, maar ook hun verbruik per toestel, zouden willen weten.

Uiteraard vond men de intuïtiviteit van het interface en duidelijke informatie belangrijk.

Men vond het belangrijk om te kunnen zien dat het apparaat werkt en een impact heeft op hun kosten.

</br>

### Conclusies & implicaties

**Ontwerpcriteria**
- Zo automatisch mogelijk
- Moet het totaalverbruik en verbruik per apparaat kunnen meten en weergeven.
- Het schakelen van apparaten, op basis van:
  - Energieprijs
  - Geproduceerde zonne-energie
  -   Voorrangsregels
  -   Limieten

- Bespaarde kosten en verbruik worden uitgedrukt in euro.
- Het apparaat moet een fysiek scherm hebben, maar een app wordt niet uitgesloten.
- Moet te installeren zijn, door de gebruiker zelf
- Het apparaat moet een esthetische mooi zijn
- Rendabel op ~3 jaar tijd.

**Key insights**
- Mensen gebruiken inderdaad de meeste energie rond de avond en de ochtend (= duurste momenten).
- Mensen met zonnepanelen hebben hetzelfde probleem als mensen met dynamische energiecontracten: Zij kunnen goedkope energie niet op het juiste moment benutten. De doelgroep zal dus aangepast worden, om ook mensen met zonnepanelen te bevatten.
- Het lijkt dat energie niet enkel ongrijpbaar is voor kinderen, maar ook voor de doorsnee volwassen gebruiker... 
- Er zal moeten gelet worden op het begrijpbaar maken van informatie omtrent energie (verbruik etc).

<br>

---

<p align="center">
  <a href="/1_Discovery.md">⬆️ Return to top</a><br>
  <a href="/README.md">🏠 Return to main<a><br>
  <a href="/LICENSE">📜 CC License</a> & <a href="/LICENSE">MIT License</a><br>

</p>

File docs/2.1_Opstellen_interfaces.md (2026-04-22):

## Opstellen interfaces
De theorie achter het opstellen van de interfaces, voor het interface onderzoek, wordt hier kort besproken. <a href="../reports and protocols/Interface protocol.pdf">Interface protocol</a> gaat dieper in op dit onderzoek. De resultaten worden besproken in <a href="../reports and protocols/Inteface report.pdf">Interface report</a>.

Bij het opstellen van de interfaces werd gebruikgemaakt van de "Gestalt wetten". Hieronder wordt per interface toegelicht hoe de "Gestalt wetten" gebruikt werden.

> [!WARNING]
> Van de besproken interfaces, worden enkel de pagina's besproken die hier relevant zijn.
> Voor een overzicht van de volledige interfaces, zie <a href="../reports and protocols/Interfaces merged.pdf">Interfaces merged</a>

### Interface 1

De grote knoppen, aan de onderkant van het scherm maken gebruik van **Similarity**(1), waardoor de onderkant van het scherm als een aparte zone gezien zou kunnen worden. Ook "year", "month" en "Week" -knoppen maken gebruik van similarity.

**law of common region**(2) werdt gebruikt om de knoppen "year", "month" en "Week" af te zonderen van de rest van het scherm.



Op pagina 2 & 3 van dit interface werd **law of common region**(2) gebruikt, om informatie te groeperen per apparaat (zoals naam en limieten).


### Interface 2

Bij interface 2 is gebaseerd op **Fitt’s law** en **Hick's law**, om de interface zo simpel mogelijk te maken. 

> ***Fitt's law***
"The time to acquire a target is a function of the distance to and size of the target."

=> Eén menu, zonder submenu's of verborgen opties, zorgt voor een snellere en intuïtievere navigatie.

> ***Hick’s law***
"The time it takes to make a decision increases with the number and complexity of
choices."

=> Een klein aantal knoppen en mogelijke interacties zorgt voor een snellere en intuïtievere navigatie.

Verder werd **law of common region**(2) gebruikt om alle instellingen te groeperen en af te zonderen van het verbruik.
Ook om deze instellingen te groeperen per apparaat werd law of common region gebruikt.

Het principe van **similarity**(1) werd toegepast op de "1 year", "1 month" en "1 Week" -knoppen.

**Continuation**(3) werd gebruikt om duidelijk te maken dat de interface verder loopt dan de gebruiker kan zien. Er kan dus nog naar beneden genavigeerd worden... Dit werd als volgt toegepast:
- Het kader rond de instellingen wordt afgesneden door de onderkant van het scherm
- het onderste apparaat wordt doormidden gesneden door de onderkant van het scherm.



### Interface 3

Opnieuw werdt het principe van **similarity** toegepast op de "day"", "week", "month" en "year" -knoppen.
Om deze knoppen af te zonderen en duidelijk te maken welke knop geselecteerd is, werdt **law of common region** gebruikt.
Opnieuw werd het principe van **similarity** toegepast op de "day", "week", "month" en "year" -knoppen.
Om deze knoppen af te zonderen en duidelijk te maken welke knop geselecteerd is, werd **law of common** region gebruikt.



### Interface 4

Knoppen die niet ingedrukt of "actief" zijn, worden weergegeven met een 3D-effect, waardoor ze lijken uit te steken. Als een knop ingedrukt is, dan lijkt deze lager te liggen dan de andere knoppen. Dit is het gebruik van **common fate**(4).

**Proximity**(5) werd gebruikt om knoppen te groeperen. De "D", "W, "M" en "J" -knoppen liggen bijvoorbeeld dicht bijeen, waardoor ze intuitief gegroepeerd worden.



<br>

---

<p align="center">
  <a href="/2.1_Opstellen_interfaces.md">⬆️ Return to top</a><br>
  <a href="/README.md">🏠 Return to main<a><br>
  <a href="/LICENSE">📜 CC License</a> & <a href="/LICENSE">MIT License</a><br>

</p>

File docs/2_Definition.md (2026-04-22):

## Definition

### Doestellingen
De doelstelling van de tweede fase, definition is om het concept te valideren, "designing the right thing".

Dit houd dus in dat we de belangrijkste onzekerheden moeten identificeren om het concept verder te ontwikkelen, zodat we hieruit conclusies kunnen nemen om onze design requirements aan te passen en zo de nodige bouwstenen hebben voor de uitwerking van het concept.

### Materiaal & methoden
#### 1. Knoppendrukker onderzoek

Hier wouden we de vorm en grootte van de knoppendrukker, het toestel dat de startknoppen van complexere apparaten hoort te besturen, in ons hoofd valideren.

We hebben hiervoor een kartonnen versie gemaakt, waarin we ook een simpele solenoide gemonteerd hebben om de functionaliteit te immiteren.

Hieruit hebben we kunnen afleiden dat dit element veel kleiner gemaakt moet worden en dat de bevestigingsmethode van dit toestel sterk genoeg zal moeten zijn om de krachten van de solenoide op te vangen.

#### 2. Interface onderzoek

In dit eerste onderzoek hebben we ons verdiept in hoe onze interface eruit kan zien en onze eigen ideëen voor wat we precies gaan weergeven, samen met het onderzoeken van waar de knelpunten zitten bij het navigeren rond de interface.

##### Onderzoeksvragen

•	Kunnen de respondenten zich gemakkelijk navigeren om een doelstelling te bereiken?

•	Waar maken de respondenten juiste assumpties en waarom?

•	Waar maken de respondenten verkeerde assumpties en waarom?

•	Waar moeten de respondenten lang of kort nadenken vooraleer ze de volgende stappen kunnen uitvoeren en waarom?

##### Werkwijze

1. De respondenten worden gevraagd om luidop te zeggen wat ze zien en denken tijdens het uitvoeren van de test.

2. Er wordt een context met een doelstelling voorgelezen waarna de respondent deze probeert te voltooien.

3. Als de respondent op een knop duwt of een beweging maakt die de interface normaal zou doen veranderen van menu, dan zal de onderzoeker het correcte menu boven op het vorige leggen. Dit wordt herhaald tot de doelstelling bereikt is.

4. Stap een en twee worden herhaald tot elke doelstelling voldaan is voor elke interface.

5. Na het onderzoek worden er nog een aantal aanvullende vragen gesteld.

Hiervoor hebben we een simpel kartonnen prototype gemaakt, waarin we meerdere bladeren A5 papier konden plaatsen, om zo de interface in een semi-realistisch omhulsel weer te geven.

Voor de papieren interfaces hebben we een reeds gemaakte interface van tijdens de discovery fase samengesteld met drie andere interfaces, door elk van ons gemaakt, om zo een totaal van vier interfaces te onderzoeken.

##### Meting

Dit onderzoek zal gemeten worden door middel van een observatie tijdens de usability test, door een video opname van het onderzoek met geluid en door een analyse te maken van de achteraf gestelde vragen.

#### 3. Functie onderzoek

In dit onderzoek wouden we het belang van een groot aantal functionaliteiten onderzoeken, zodat we de primaire, secundaire en onnodige functies kunnen vastleggen.

##### Onderzoeksvragen

- Welke functies zijn van belang om aan de volgende concept doelen te voldoen?
    -  Verloren energie zonnepanelen laten verbruiken
    - Gebruiker bewust maken van hun verbruik
    - Gebruiker helpen / nudgen om te besparen thuis
  </br>
- Willen gebruikers hun energieverbruik weten of diepgaand begrijpen?
    - Hoeveelheid data die beschikbaar is
  </br>
- Hoe aanwezig mag het systeem zijn in huis?

    - Zeer actief sturen
    - Lichtjes nudgen / tips geven
    - Uitsluitend informeren

##### Plan van aanpak
###### 1.	Deel I – Nodige functies per scenario bepalen

Hier zullen we zoeken naar de belangrijkste functies van het apparaat, zodat we de gebruiker in specifieke scenario’s waar we ons op richten in te helpen.

###### 2.	Deel II – Algemene nood van functies bepalen

Hier wordt er nog gepolst naar het algemene belang van de functies.

Op deze manier kan er vergeleken worden welke functies altijd toegankelijk moeten zijn en welke functies eerder nuttig zijn voor specifieke scenario’s, en bijvoorbeeld in een verder submenu kunnen zitten.

###### 3.	Nagesprek – Overleggen met de deelnemer over hun keuzes

In het nagesprek zullen we de gemaakte keuzes overleggen en ondervragen om meer inzicht te krijgen in de redenering en achterliggende noden van de gebruikers.

### Resultaten

Beide onderzoeken tonen dat gebruikers vaak moeite hebben met navigatie, iconen en terminologie in onze opgestelde interfaces.

Respondenten verwachten een centraal homescreen en directe toegang tot belangrijke functies. Grafieken worden regelmatig als onduidelijk ervaren door het ontbreken van cijfers, assen, gemiddeldes en totalen.

Veel gebruikers verkiezen visuele informatie boven auditieve signalen.

De waardering van functies verschilt sterk per context en situatie. Sommige gebruikers focussen op algemeen energieverbruik, anderen op kosten of vermogen. 

Automatische sturing wordt verschillend geïnterpreteerd, afhankelijk van vertrouwen en ervaring. Gebruikers geven aan dat systemen moeten aansluiten bij hun persoonlijke voorkeuren en thuissituatie.

Energieverbruik moet in beide euro's en wattage gegeven worden, omdat mentale modellen verschillen in verband met energieverbruik.

### Conclusies & implicaties
De belangrijkste conclusies die we uit dit onderzoek kunnen halen zijn als volgt:

- De interface moet verbruik van vandaag kunnen tonen

- Verbruik moet cijfers en totalen bevatten

- Belangrijke functies moeten direct bereikbaar zijn, niet diep in menu’s

- Het systeem moet functies contextafhankelijk aanbieden

- Het systeem moet primair visueel communiceren, niet via audio

- Automatisering moet controleerbaar en begrensd zijn

- Het systeem moet zowel wattage als euro’s kunnen tonen

- Het systeem moet modulair uitbreidbaar zijn volgends de noden van de gebruiker (basis + extra’s)

- Het systeem moet meldingen doseren om informatie-overload te vermijden

<br>

---

<p align="center">
  <a href="/2_Definition.md">⬆️ Return to top</a><br>
  <a href="/README.md">🏠 Return to main<a><br>
  <a href="/LICENSE">📜 CC License</a> & <a href="/LICENSE">MIT License</a><br>

</p>

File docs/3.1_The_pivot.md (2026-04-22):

## The pivot :arrows_counterclockwise:

Na een tussentijdse evaluatie, met feedback van de mentoren, werd beslist om onze focus licht te verleggen en de doelgroep aan te passen.

### Development focus :mag:

Uit de eerste user interviews bleek dat er geen consensus was over app versus fysiek scherm als interface... Eerder werd gekozen om toch een fysiek scherm te ontwikkelen.

Er bestaan echter al heel wat schermen en interfaces die energieverbruik weergeven, bovendien heeft het fysiek scherm weinig meerwaarde tegenover een smartphone-app.
Hierdoor werd toch besloten om te focussen op een app en de fysieke interface achterwege te laten...
> [!NOTE] 
>De conclusies van het interface onderzoek blijven nuttig, voor de ontwikkeling van de app.

Er werd ook besloten om meer in te spelen op het automatiseren van "domme" apparaten en minder op het duurzaamheids- en besparingsgedeelte.

Aangezien slimme stekkers ook al bestaan, en de knoppencontroller het meest interessante object is om op verder te werken, wordt enkel verder gewerkt aan de knoppencontroller.

### Doelgroep :family:

De doelgroep, waar tot nu toe voor ontworpen werd is: *Mensen in bezit van zonnepanelen die willen besparen maar geen budget hebben voor batterijen*.

Door de lichtte verandering van focuspunt, verandert de doelgroep, van *zonnepaneelhouders* naar home-hackers, gadgeteers & tech-enthousiasts.

De nieuwe doelgroep is dus:
*Mensen die graag hun huis "hacken" en "domme" apparaten willen automatiseren*.

<br>

---

<p align="center">
  <a href="/3.1_The_pivot.md">⬆️ Return to top</a><br>
  <a href="/README.md">🏠 Return to main<a><br>
  <a href="/LICENSE">📜 CC License</a> & <a href="/LICENSE">MIT License</a><br>

</p>

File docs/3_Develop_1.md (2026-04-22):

## Develop 1

### Doelstellingen
Aangezien er net [een pivot](3.1_The_pivot.md) achter de rug is, was in de eerste plaats belangrijk om inzichten te verkrijgen in onze nieuwe doelgroep. 

Ten tweede moest er onderzocht worden welk actuator of motor het best zou werken voor het indrukken van de bedieningsknoppen van een wasmachine of droogkast.

### Methoden

#### 1. Schematische ontleding + ideation

Om het vervolg van het ontwerpproces te ondersteunen werden enkele schemas opgesteld. Deze bieden steun doorheen de komende fasen van het ontwerpen.

Eerst werd er een Hierarchical Task Analysis (HTA) opgesteld:
<p align="center">
  
</p>

Vervolgens werd het product opgesplitst in zijn verschillende functies, aan de hand van een functienalayse:
<p align="center">
  
</p>

Voor elk van die functies, afzonderlijk, werden oplossingen bedacht.

De HTA en gegenereerde ideeën werden samengegoten in één gedetailleerd schema, waarin human-product interacties, functies, mogelijke deeloplossingen en de interactie tussen die componenenten worden weergegeven.
<p align="center">
  
</p>

> [!TIP]
> Om bovenstaande afbeelding in detail te bekijken:
> 1. Linksklik op de afbeelding
> 2. Rechtsklik op de afbeelding
> 3. Klik op "Open image in new tab"

<br>

#### 2. User interview (N=3)

Om meer inzichten te verkrijgen in de wensen en/of eisen van de gebruikers, werden opnieuw user interviews afgelegd. Daarbij worden vragen gesteld aan de gebruiker, die gericht zijn op het beantwoorden van onzekerheden in deze fase:
- Zien de gebruikers een meerwaarde in het product, welke?
- Is er interesse in het product?
- Meerwaarde tegenover enkel slimme stekkers kopen?
- Wat maakt dit meer dan enkel een coole gadget?
- Hoeveel setuptijd is acceptabel?
- Hoe vaak zouden mensen iets willen automatiseren?
- Wat willen mensen automatiseren?
- Verkopen als bouwpakket?
- Pains identificeren waarop ingespeeld kan worden?

Voor meer detail over dit onderzoek zie <a href="../reports and protocols/Protocol interview after pivot.pdf">Protocol interview after pivot</a>.

<br>

#### 3. Fysieke tests aan de hand van prototypes

<p>
  <br>Om te onderzoeken welke electronische componenten het best zouden werken voor deze toepassing, werd eerste een eerste eliminatie uitgevoerd, op basis van voorkennis. Vervolgens werden voor de overblijvende actuatoren, prototypes gebouwd. Deze prototypes werden op een wasmachine aangebracht en geactiveerd. Op die mannier werd getest of de prototypes in staat waren om de knoppen van de wasmachine in te drukken. Voor meer detail of een blik op de gebruikte prototypes, zie <a href="../reports and protocols/1. Drukken van knoppen protocol.pdf">Drukken van knoppen protocol</a>.
</p>
 
<br clear="left" />

### Resultaten
De resultaten van beide onderzoeken worden kort besproken.

#### 1. User interview (N=3)
Uit deze user interviews is gebleken dat de grootste redenen voor automatisatie, energiebesparing en comfort zijn. Energiebesparing gaat onderliggend echter om geldbesparing.

De meeste gebruikers zouden dit product gebruiken, voor het slim maken van domme apparaten. 
De meerwaarde zit daarbij wel in het selecteren van specifieke programma’s.
Ook is gebleken dat men het een nadeel zou vinden, als er geen verbruik uitgelezen kan worden...

De volgende zaken zijn bij alle gebruikers naar boven gekomen:
- De koopprijs mag wel een redelijke investering zijn, zolang er voldoende meerwaarde in zit, het geld moet terugverdient kunnen worden.
- De keuze voor meldingen te krijgen of niet is ook gevraagd, aangezien dat zeer subjectief is per persoon.
- Herbruikbaarheid, gebruiksvriendelijkheid en eventueel ook compatibiliteit met andere systemen
- Alarmmeldingen
- Betrouwbaarheid, bedrijfszekerheid
- Lage setuptijd, eenmalig uit te voeren waarna het toestel grotendeels zelfstandig dient te werken.
- Makkelijk te integreren bij apparaten
- Geen bouwpakket

<br>

#### 2. Fysieke tests

Dit is de resulterende tabel, waarin de subjectieve beoordeling van de verschillende componenten in staat:

|  | Kan knop indrukken? | Kracht |	Feedbackloop | Gewicht | Gemak aansturen (extra componenten + code) |
|----|----|----|----|----|----|
|**Servo**	|Ja	|Matig	|Ja => hoge precisie + herhaalbaarheid	|Matig	|Matig|
|**Stepper (niet op knop getest)**	|? (Waarschijnlijk)	|Matig	|Nee (Maar hoge precisie + herhaalbaarheid, bij geen slip)	|Zwaar	|Moeilijk|
|**Solenoide**	|Nee	|Laag	|Nee (niet per se nodig) |Zwaar	|Makkelijk|
|**Lineaire actuator**	|Ja	|Zeer Hoog	|Nee	|Matig	|Makkelijk|
|**Brushed + geared**	|Ja	|Zeer Hoog	|Nee	Zwaar	|Makkelijk|

<br>

### Conclusies & implicaties
Hier worden de conclusies en implicaties voor het product, kort besproken.
Voor een meer gedetailleerde bespreking van de resultaten zie <a href="../reports and protocols/1. Drukken van knoppen report.pdf">Drukken van knoppen report</a> en <a href="../reports and protocols/Report interview after pivot.pdf">Report interview after pivot</a>.

#### Product requirements
- De knoppencontroller kan specifieke programma’s uitvoeren
- De knoppencontroller is betrouwbaar
- De knoppencontroller is herbruikbaar
- De knoppencontroller is makkelijk te integreren, zonder demontage
- De knoppencontroller kan ingesteld worden in minder dan vijf minuten
- De knoppencontroller kan zijn waarde terugverdienen binnen de 3 jaar
- De knoppencontroller kan zelfstandig werken
- De app geeft alarmmeldingen
- De app heeft de mogelijkheid om meldingen in/uit te schakelen

#### Key insights
- Er is interesse in het product:
De gebruikers zijn geïntresseerd in een product dat apparaten slim maakt, zodat er op die manier meer comfort is en geld bespaard word.
<br>
- De slimme stekkers (al bestaand) zijn nog steeds een nuttige toevoeging aan ons product. Aangezien gebruikers nog steeds wensen het energieverbruik af te lezen.
<br>
- De brushed DC motor gecombineerd met een schroefmechanisme (= lineaire actuator), is de best passende oplossing voor het indrukken van knoppen op een wasmachine.

<br>

---

<p align="center">
  <a href="/3_Develop_1.md">⬆️ Return to top</a><br>
  <a href="/README.md">🏠 Return to main<a><br>
  <a href="/LICENSE">📜 CC License</a> & <a href="/LICENSE">MIT License</a><br>

</p>

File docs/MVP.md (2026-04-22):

## Minimum viable product

Voor ons ontwerp zijn de volgende aspecten nodig om het een MVP te kunnen noemen:

* Meerdere knoppen moet ingedrukt kunnen worden
* Eén draaiknop moet bestuurd kunnen worden
* Het apparaat moet bevestigd kunnen worden op een wasmachine 

<br>

---

<p align="center">
  <a href="/README.md">🏠 Return to main<a><br>
  <a href="/LICENSE">📜 CC License</a> & <a href="/LICENSE">MIT License</a><br>

</p>

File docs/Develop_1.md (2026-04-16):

## Develop 1

### Doelstellingen
Aangezien er net [een pivot](The_Pivot.md) achter de rug is, was in de eerste plaats belangrijk om inzichten te verkrijgen in onze nieuwe doelgroep. 

Ten tweede moest er onderzocht worden welk actuator of motor het best zou werken voor het indrukken van de bedieningsknoppen van een wasmachine of droogkast.

### Methoden

#### 1. Schematische ontleding + ideation

Om het vervolg van het ontwerpproces te ondersteunen werden enkele schemas opgesteld. Deze bieden steun doorheen de komende fasen van het ontwerpen.

Eerst werd er een Hierarchical Task Analysis (HTA) opgesteld:
<p align="center">
  
</p>

Vervolgens werd het product opgesplitst in zijn verschillende functies, aan de hand van een functienalayse:
<p align="center">
  
</p>

Voor elk van die functies, afzonderlijk, werden oplossingen bedacht.

De HTA en gegenereerde ideeën werden samengegoten in één gedetailleerd schema, waarin human-product interacties, functies, mogelijke deeloplossingen en de interactie tussen die componenenten worden weergegeven.
<p align="center">
  
</p>

> [!TIP]
> Om bovenstaande afbeelding in detail te bekijken:
> 1. Linksklik op de afbeelding
> 2. Rechtsklik op de afbeelding
> 3. Klik op "Open image in new tab"

<br>

#### 2. User interview (N=3)

Om meer inzichten te verkrijgen in de wensen en/of eisen van de gebruikers, werden opnieuw user interviews afgelegd. Daarbij worden vragen gesteld aan de gebruiker, die gericht zijn op het beantwoorden van onzekerheden in deze fase:
- Zien de gebruikers een meerwaarde in het product, welke?
- Is er interesse in het product?
- Meerwaarde tegenover enkel slimme stekkers kopen?
- Wat maakt dit meer dan enkel een coole gadget?
- Hoeveel setuptijd is acceptabel?
- Hoe vaak zouden mensen iets willen automatiseren?
- Wat willen mensen automatiseren?
- Verkopen als bouwpakket?
- Pains identificeren waarop ingespeeld kan worden?

Voor meer detail over dit onderzoek zie <a href="../reports and protocols/Protocol interview after pivot.pdf">Protocol interview after pivot</a>.

<br>
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

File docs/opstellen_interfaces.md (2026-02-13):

## Opstellen interfaces
De theorie achter het opstellen van de interfaces, voor het interface onderzoek, wordt hier kort besproken. <a href="../reports and protocols/Interface protocol.pdf">Interface protocol</a> gaat dieper in op dit onderzoek. De resultaten worden besproken in <a href="../reports and protocols/Inteface report.pdf">Interface report</a>.

Bij het opstellen van de interfaces werd gebruik gemaakt van de "Gestalt wetten". Hieronder wordt per interface toegelicht, hoe de "Gestalt wetten" gebruikt werden.
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

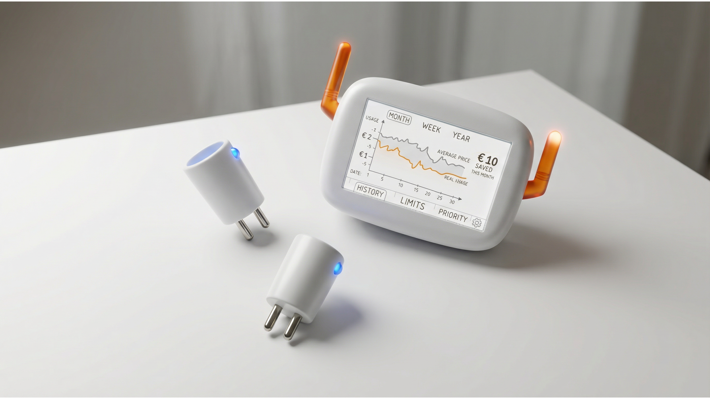
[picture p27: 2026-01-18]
img/Hero1.png

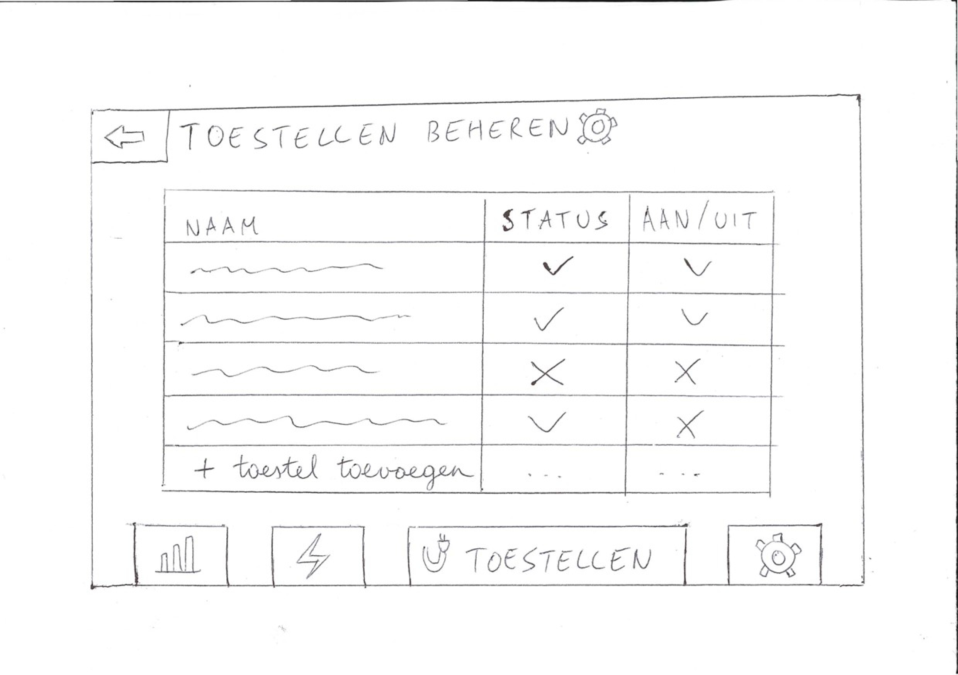
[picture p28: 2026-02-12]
img/Interface4 pg7.jpg

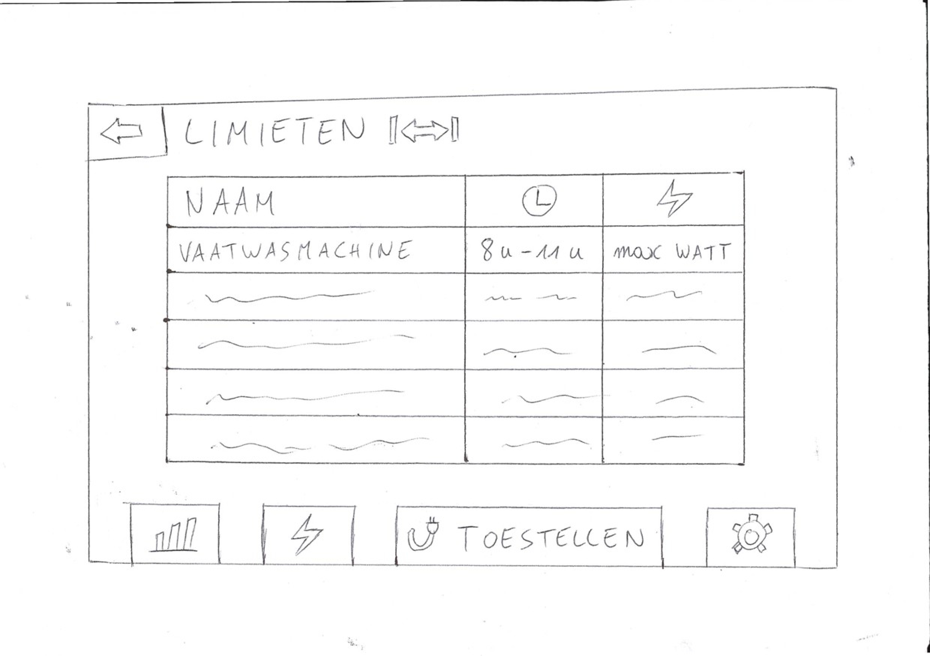
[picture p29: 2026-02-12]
img/Interface4 pg6.jpg

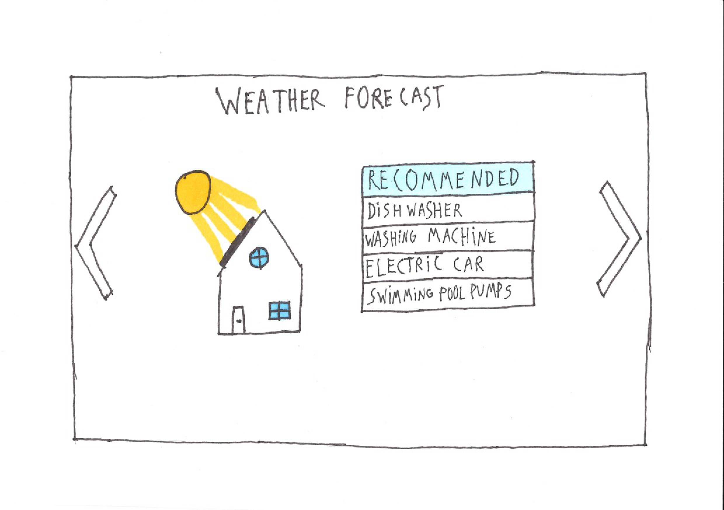
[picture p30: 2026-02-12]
img/Interface3 pg3.jpg

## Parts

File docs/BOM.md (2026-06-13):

# Bills of materials

Deze repository bevat de materialenlijst voor het project.  
Alle onderdelen zijn hieronder opgesomd met werkende links naar voorbeeldproducten of officiële documentatie.

> [!WARNING]
>De links dienen als referentie.  
Gelijkwaardige onderdelen van andere leveranciers zijn ook geschikt.

## Benodigde materialen
- **Arduino UNO**  
  https://www.amazon.de/-/nl/dp/B007R9TUJE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

- **Servomotor**  
  [https://www.amazon.de/-/nl/dp/B0CP7RR3F5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](https://www.amazon.de/-/nl/dp/B0D3DG9JDJ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)

- **Steppermotor**  
  https://www.amazon.de/-/nl/dp/B0CW9ST4XM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

- **Potentiometer**  
  https://www.amazon.de/-/nl/dp/B01NCAJHZB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

- **Breadboard + jumper wires**  
Breadboard: https://www.amazon.de/dp/B07KKJSFM1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  
Jumper wires: https://www.amazon.de/dp/B07KKJSFM1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

- **Externe regelbare voeding**
  https://www.amazon.de/dp/B0D3PVL1V7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  

<br>

---

<p align="center">
  <a href="/BOM.md">⬆️ Return to top</a><br>
  <a href="/README.md">🏠 Return to main<a><br>
  <a href="/LICENSE">📜 CC License</a> & <a href="/LICENSE">MIT License</a><br>

</p>

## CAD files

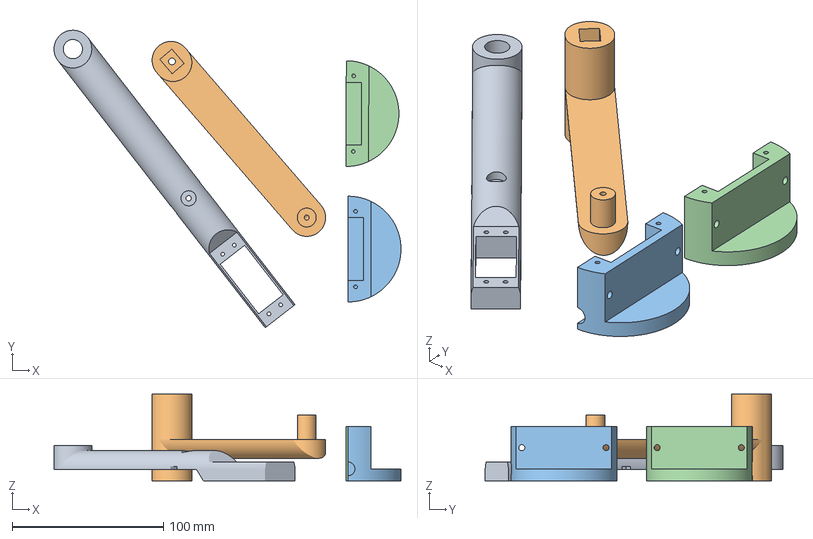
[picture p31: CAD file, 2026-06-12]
cad/rotating pivot arm/fullprint.3mf
229.7 x 197.0 x 57.5 mm
arm_close
arm_far
Split Body (5)

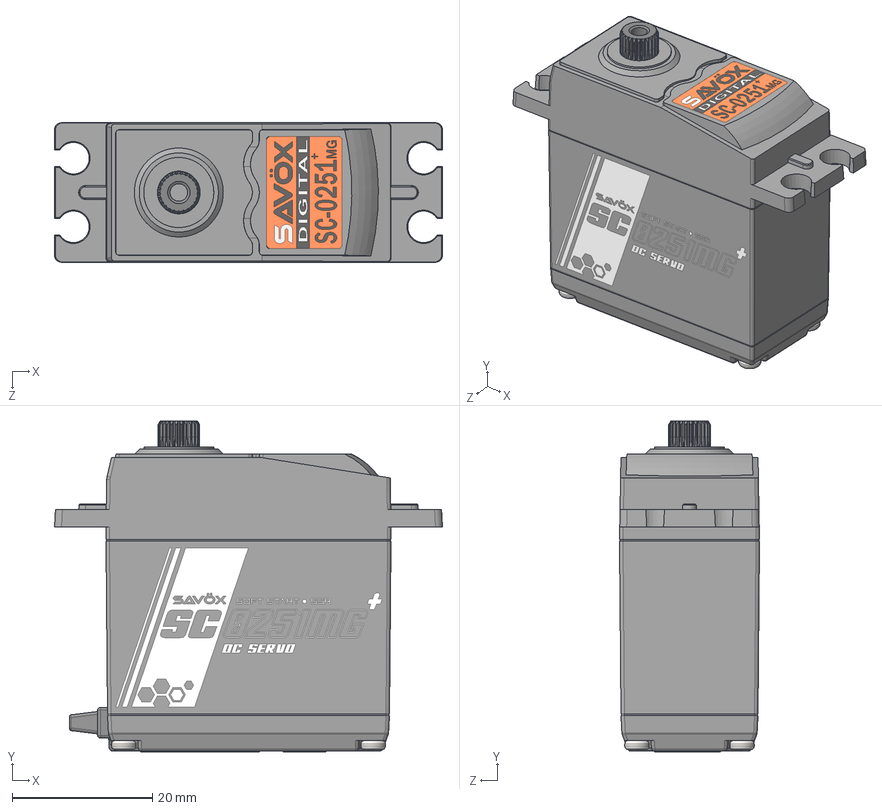
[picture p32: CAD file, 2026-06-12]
cad/rotating pivot arm/V2/sc-0251mgp.STEP
55.4 x 47.2 x 20.0 mm

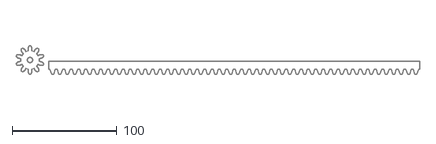
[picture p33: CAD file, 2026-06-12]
cad/rotating slider arm/V2/laser (10).dxf
384.5 x 27.0

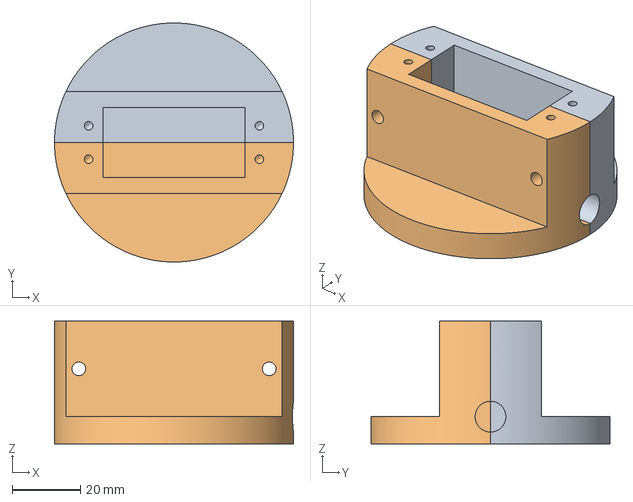
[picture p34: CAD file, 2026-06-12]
cad/rotating pivot arm/base.3mf
70.0 x 70.0 x 36.0 mm
Split Body (5)

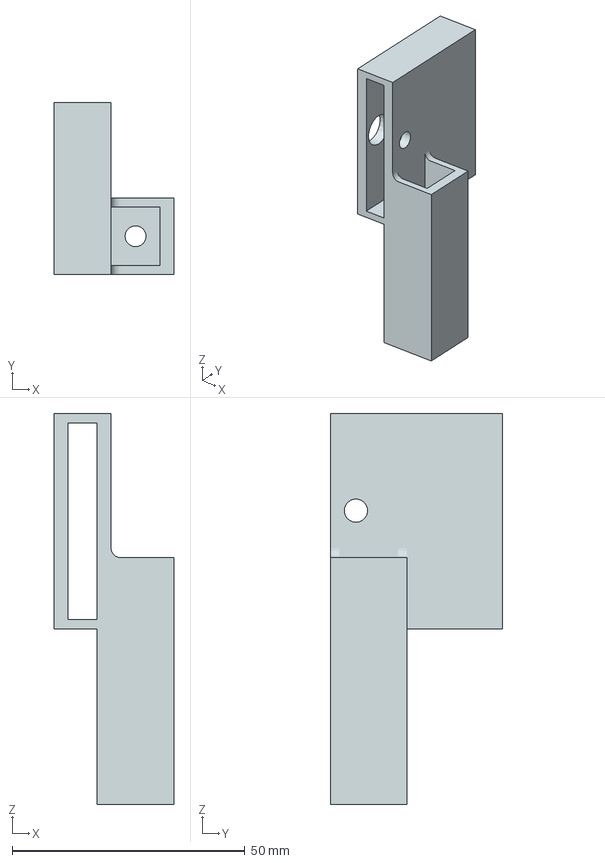
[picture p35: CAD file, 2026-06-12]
cad/rotating slider arm/V2/Slider_1.3mf
25.8 x 37.0 x 83.9 mm

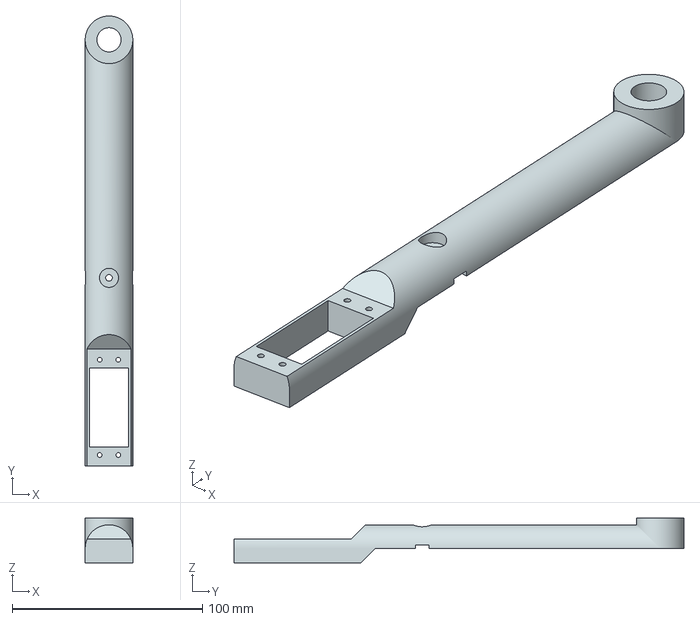
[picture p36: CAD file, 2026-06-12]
cad/rotating pivot arm/arm_close.3mf
25.0 x 236.3 x 23.5 mm

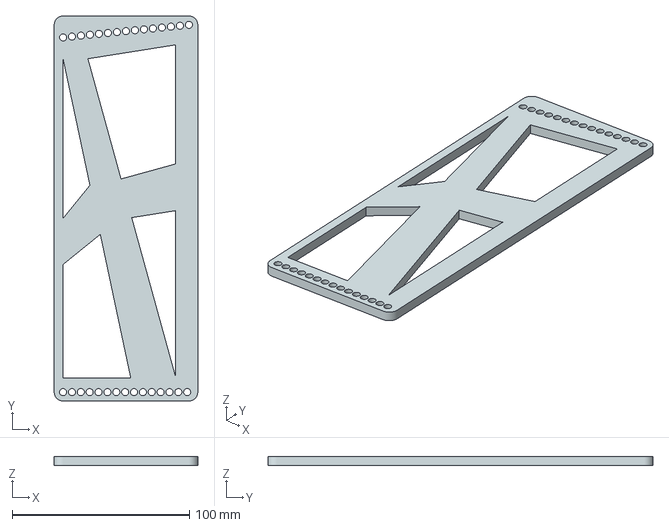
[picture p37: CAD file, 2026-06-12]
cad/rotating pivot arm/test belt afstanden.3mf
81.0 x 217.1 x 5.00 mm

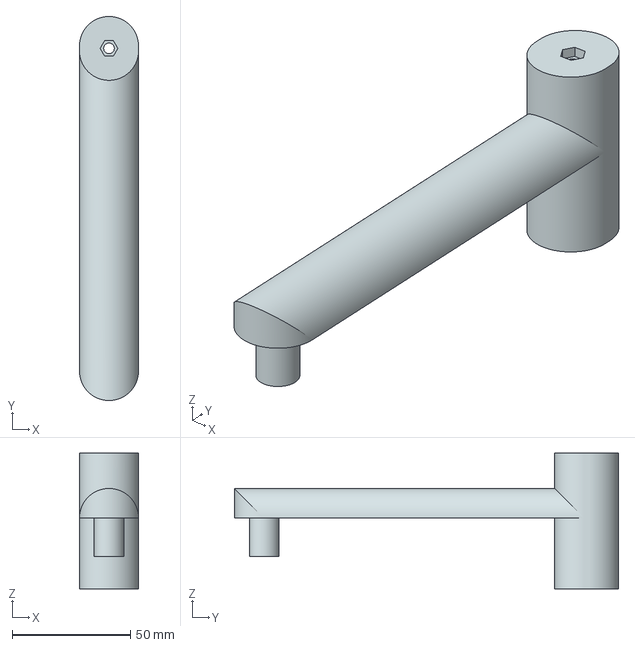
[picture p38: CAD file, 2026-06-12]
cad/rotating pivot arm/arm_far.3mf
25.0 x 162.5 x 57.5 mm

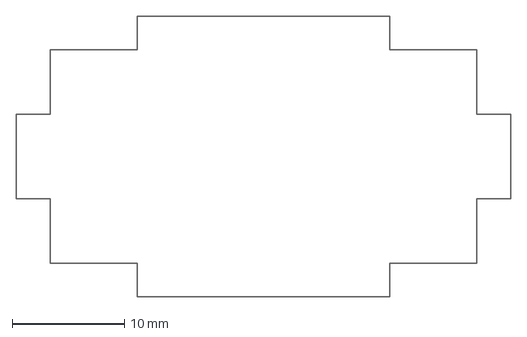
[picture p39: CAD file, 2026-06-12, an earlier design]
cad/rotating pivot arm/V1/DXF lasercut/centralbox lasercut - front plate - 2x.dxf
44.0 x 25.0 mm

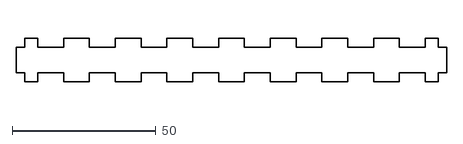
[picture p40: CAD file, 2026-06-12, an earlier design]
cad/rotating pivot arm/V1/imported files/box-front.dxf
150.0 x 15.0

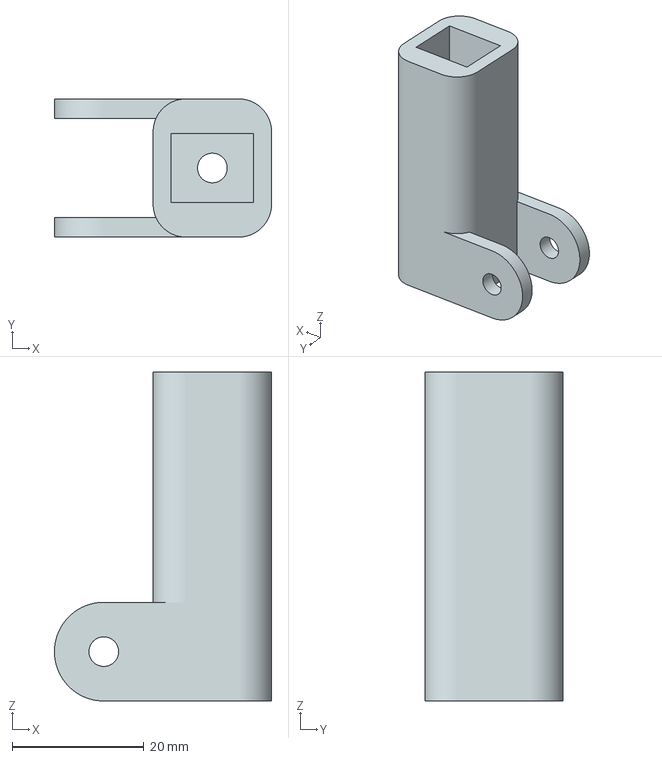
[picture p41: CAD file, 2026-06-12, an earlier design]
cad/rotating pivot arm/V1/Lineair actuator holder.3mf
33.0 x 21.0 x 50.0 mm

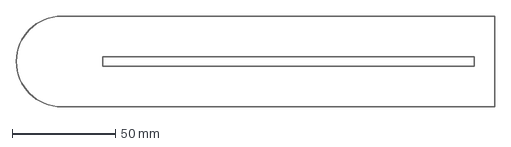
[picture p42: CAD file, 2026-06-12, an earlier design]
cad/rotating slider arm/V1/Robot_Rotating_3.dxf
232.0 x 44.0 mm

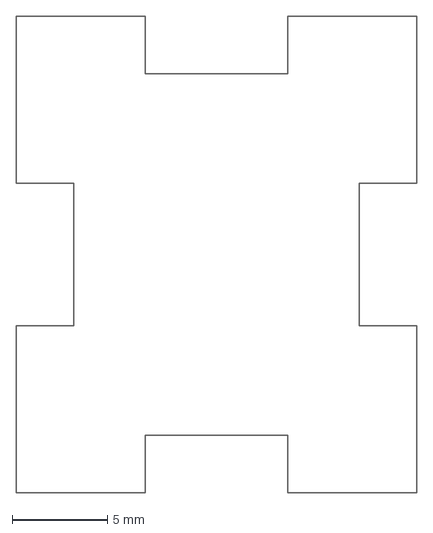
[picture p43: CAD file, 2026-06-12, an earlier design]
cad/rotating pivot arm/V1/DXF lasercut/centralbox lasercut - side plate - 1x.dxf
21.0 x 25.0 mm

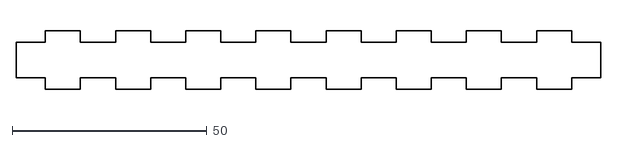
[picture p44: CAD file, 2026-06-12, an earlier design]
cad/rotating pivot arm/V1/imported files/box-bottom.dxf
150.0 x 15.0

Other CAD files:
cad/rotating slider arm/V2/Rotating_sliding_arm_V2_1.3mf
cad/rotating slider arm/V1/Robot_Rotating.dxf
cad/rotating pivot arm/V1/DXF lasercut/arm ver - top - 2x.dxf
cad/rotating pivot arm/V1/imported files/SM-S2309S-Arm.SLDPRT
cad/rotating pivot arm/V1/Arm dicht lasercut.prt
cad/rotating pivot arm/V1/Brushed DC motor with gearbox.prt
cad/rotating pivot arm/V1/Central box.prt
cad/rotating pivot arm/V1/DXF lasercut/Arm dicht lasercut - long side - 2x.dxf
cad/rotating pivot arm/V1/DXF lasercut/Arm dicht lasercut - long top - 2x.dxf
cad/rotating pivot arm/V1/DXF lasercut/Arm dicht lasercut - small side - 2x.dxf
cad/rotating pivot arm/V1/DXF lasercut/arm ver - bottom plate - 1x.dxf
cad/rotating pivot arm/V1/DXF lasercut/arm ver - side large - 2x.dxf
cad/rotating pivot arm/V1/DXF lasercut/arm ver - side large - 2x_bk.dxf
cad/rotating pivot arm/V1/DXF lasercut/arm ver - side small - 2x.dxf
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

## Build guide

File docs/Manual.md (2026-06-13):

# Handleiding voor het laatste prototype
## Benodigde materialen

### Elektronica

| Component | Aantal |
|---|---|
| Arduino UNO | 1 |
| Servomotor | 1 |
| Steppermotor | 1 |
| Potentiometer | 1 |
| Breadboard | 1 |
| Jumper wires | Meerdere |

### Mechanische onderdelen

| Component | Aantal |
|---|---|
| 3D-geprinte onderdelen | Zie STL-bestanden |
| M3 bouten | Diverse |
| M3 moeren | Diverse |
| Secondelijm | 1 |

### Aankooplinks

- **Arduino UNO**  
  https://www.amazon.de/dp/B007R9TUJE

- **Servomotor**  
  https://www.amazon.de/dp/B0CP7RR3F5

- **Steppermotor**  
  https://www.amazon.de/dp/B0CW9ST4XM

- **Potentiometer**  
  https://www.amazon.de/dp/B01NCAJHZB

- **Breadboard**  
  https://www.amazon.de/dp/B07KKJSFM1

- **Jumper wires**  
  https://www.amazon.de/dp/B07KKJSFM1

- **Externe regelbare voeding**  
  https://www.amazon.de/dp/B0D3PVL1V7

## Schakeling
### Elektronische onderdelen

AEOM maakt gebruik van een eenvoudige maar modulaire elektronica-opbouw rond een **Arduino UNO**. Het systeem combineert een **servomotor** voor het bedienen van draaiknoppen en een **stappenmotor** voor het positioneren van de arm.

#### Elektrisch schema

<p align="center">
  
</p>

#### Gebruikte componenten

| Component | Functie |
|---|---|
| Arduino UNO | Hoofdcontroller van het systeem |
| SG90 Servomotor | Bediening van draaiknoppen |
| 28BYJ-48 Steppermotor | Positionering van de arm |
| ULN2003 Driver Board | Aansturing van de steppermotor |
| Potentiometers | Handmatige invoer voor de gebruiker |
| Breadboard | Prototype-opstelling |
| Jumper wires | Elektrische verbindingen |
| Externe 5V voeding | Voeding voor servo en steppermotor |

### Aansluitingen

#### Servo (SG90)

| Servo | Arduino |
|---|---|
| Signaal | Pin 3 |
| Voeding | Externe 5V |
| GND | Gemeenschappelijke GND |

#### Steppermotor (28BYJ-48)

| ULN2003 | Arduino |
|---|---|
| IN1 | Pin 8 |
| IN2 | Pin 9 |
| IN3 | Pin 10 |
| IN4 | Pin 11 |

De ULN2003-driver wordt gevoed door een externe 5V-voeding en is verbonden met de 28BYJ-48 steppermotor.

#### Potentiometers

| Potentiometer | Arduino |
|---|---|
| Pot 1 | A0 |
| Pot 2 | A1 |
| VCC | 5V |
| GND | GND |

### Voeding

De servo en steppermotor worden gevoed via een **externe 5V-voeding**. Dit voorkomt spanningsvallen en instabiliteit die kunnen optreden wanneer de motoren rechtstreeks via de Arduino worden gevoed.

> **Belangrijk:** De GND van de externe voeding moet verbonden worden met de GND van de Arduino zodat alle componenten dezelfde referentiespanning delen.

### Werking

1. De Arduino leest de waarden van beide potentiometers via de analoge ingangen A0 en A1.
2. Op basis van deze input wordt de positie van de steppermotor bepaald.
3. De steppermotor wordt aangestuurd via de ULN2003-driver.
4. De servomotor wordt rechtstreeks bestuurd via een PWM-signaal op pin 3.
5. De externe voeding levert voldoende stroom voor beide motoren terwijl de Arduino de besturingslogica verzorgt.

### Ontwerpkeuze

Deze elektronica-opbouw werd gekozen omdat ze:

- Eenvoudig te prototypen is.
- Gebruikmaakt van goedkope en makkelijk verkrijgbare componenten.
- Modulair uitbreidbaar is.
- Betrouwbaar werkt voor zowel positionering als knopbediening.
- Een duidelijke scheiding maakt tussen logica (Arduino) en vermogen (motoren).

Hierdoor blijft het systeem stabiel, onderhoudsvriendelijk en eenvoudig reproduceerbaar.
## Constructie

AEOM is ontworpen als een volledig 3D-geprint prototype. Alle structurele onderdelen werden geproduceerd via FDM 3D-printing en zijn modulair opgebouwd zodat onderdelen eenvoudig vervangen of aangepast kunnen worden.

### Montage

- Alle geprinte onderdelen worden samengebouwd met standaard M3-bouten en M3-moeren.
- De Arduino, potentiometer en motoren worden bevestigd in de daarvoor voorziene houders.
- De steppermotor wordt gemonteerd in de motorhouder van het positioneringsmechanisme.
- Na montage wordt het aandrijftandwiel op de motoras geplaatst en uitgelijnd.
- Om speling te voorkomen wordt het tandwiel permanent bevestigd met secondelijm.
- De servomotor wordt gemonteerd in de armconstructie voor het bedienen van draaiknoppen.
- Na montage worden alle kabels aangesloten via een breadboard met jumper wires.
<p align="center">
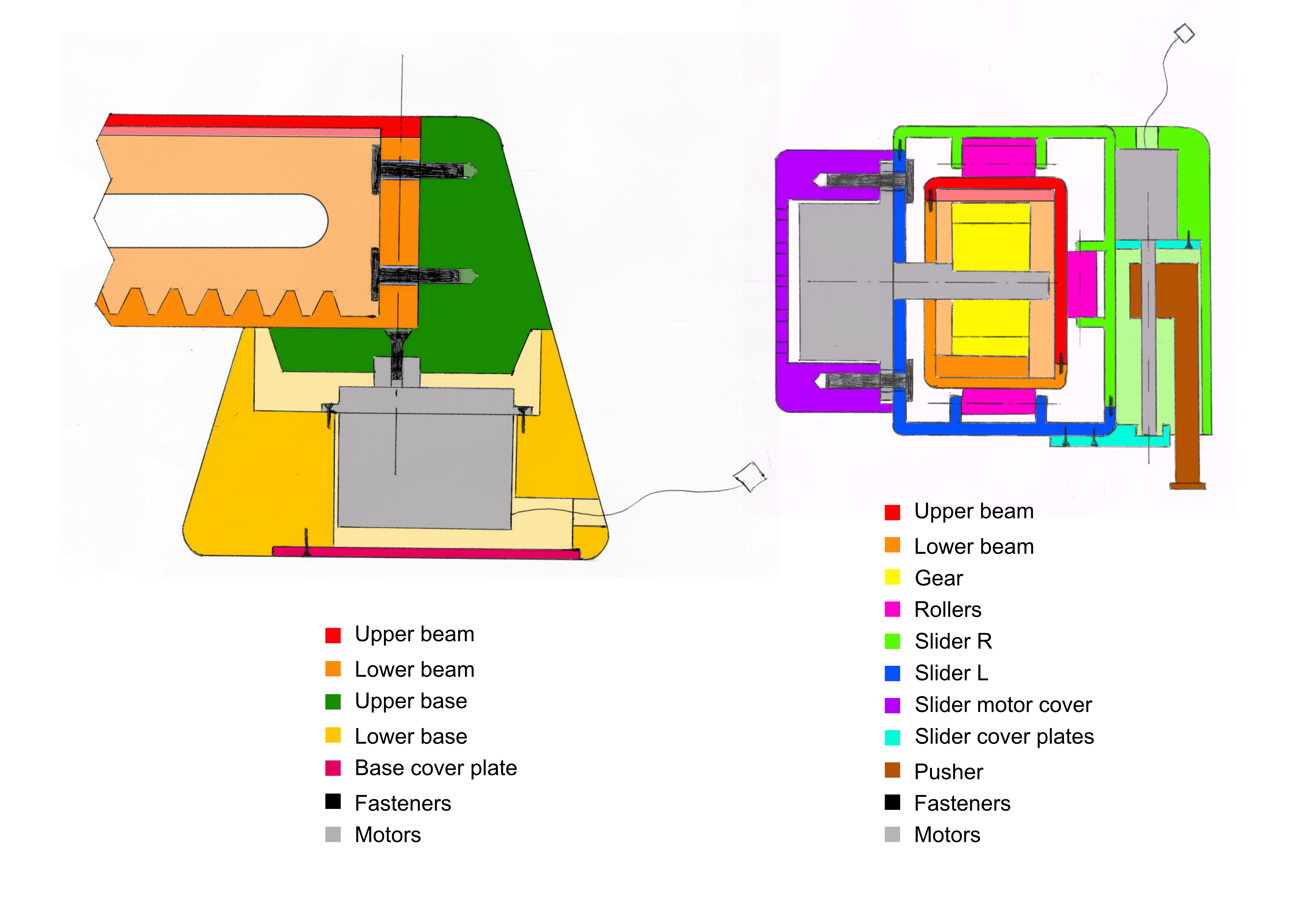
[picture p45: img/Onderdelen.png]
  
</p>

### Montagevolgorde

1. Print alle STL-bestanden.
2. Monteer het hoofdframe met M3-bouten en moeren.
3. Monteer de bewegende arm.
4. Bevestig de steppermotor in de motorhouder.
5. Plaats het tandwiel op de motoras.
6. Verlijm het tandwiel met secondelijm.
7. Monteer de servomotor.
8. Bevestig de Arduino UNO.
9. Sluit de potentiometer aan.
10. Verbind alle componenten met jumper wires via het breadboard.
11. Upload de software naar de Arduino.
12. Test en kalibreer het systeem.

### Opmerking

Het volledige prototype is ontworpen volgens een **Design for Assembly (DFA)** principe. Door uitsluitend gebruik te maken van 3D-geprinte onderdelen, standaard M3-bevestigingsmateriaal en een beperkt aantal elektronische componenten blijft het systeem eenvoudig te produceren, assembleren en onderhouden.

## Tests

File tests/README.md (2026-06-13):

Dit is een code voor het testen van de servo's

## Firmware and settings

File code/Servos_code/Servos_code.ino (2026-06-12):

#include <Servo.h>

Servo servo1;
Servo servo2;

const int pot1Pin = A0;
const int pot2Pin = A1;

int pot1Value;
int pot2Value;

int servo1Angle;
int servo2Angle;

void setup() {
  Serial.begin(9600);

  servo1.attach(3);
  servo2.attach(5);
}

void loop() {
  // Lees potmeters
  pot1Value = analogRead(pot1Pin);
  pot2Value = analogRead(pot2Pin);

  // Zet om naar servohoeken
  servo1Angle = map(pot1Value, 0, 1023, 0, 180);
  servo2Angle = map(pot2Value, 0, 1023, 0, 180);

  // Beweeg servo’s
  servo1.write(servo1Angle);
  servo2.write(servo2Angle);

  // Debug output
  Serial.print("Servo 1: ");
  Serial.print(servo1Angle);
  Serial.print("° | Servo 2: ");
  Serial.print(servo2Angle);
  Serial.println("°");

  delay(10);
}

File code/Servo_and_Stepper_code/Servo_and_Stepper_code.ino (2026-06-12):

#include <Servo.h>
#include <Stepper.h>

// ===== SERVO =====
Servo servo1;
const int pot1Pin = A0;

// ===== STEPPER =====
const int stepsPerRevolution = 2048;

// BELANGRIJK: juiste volgorde!
Stepper myStepper(stepsPerRevolution, 9, 11, 8, 10);

const int pot2Pin = A1;

void setup() {
  Serial.begin(9600);

  servo1.attach(3);

  myStepper.setSpeed(10); // basis snelheid
}

void loop() {

  // ===== SERVO BESTURING =====
  int pot1Value = analogRead(pot1Pin);
  int servoAngle = map(pot1Value, 0, 1023, 0, 180);

  servo1.write(servoAngle);

  // ===== STEPPER BESTURING =====
  int pot2Value = analogRead(pot2Pin);

  int deviation = pot2Value - 512;

  if (abs(deviation) > 50) {  // deadzone

    int snelheid = map(abs(deviation), 50, 512, 5, 15);

    myStepper.setSpeed(snelheid);

    if (deviation > 0) {
      myStepper.step(10);   // rechts draaien
    } else {
      myStepper.step(-10);  // links draaien
    }
  }

  // ===== DEBUG =====
  Serial.print("Servo: ");
  Serial.print(servoAngle);
  Serial.print(" | Stepper potentio: ");
  Serial.println(pot2Value);
}

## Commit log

2025-11-19 Update design requirements with user interview data
    Heb er bij een paar de bronnen gezet
2025-11-19 Fix formatting in design requirements table
    Klein foutje gemaakt bij de vorige nu gefixt
2026-01-19 Update bill of materials with detailed components list
    Deze repository bevat een uitgebreide materialenlijst voor het project, inclusief links naar voorbeeldproducten en officiële documentatie.
2026-01-19 Update headings and improve formatting in bom.md
2026-04-19 Fix spelling and grammar in methodologie.md
    Corrected spelling and grammatical errors throughout the document, including changes to the terms 'gebasseert' to 'gebaseerd', 'vollop' to 'volop', and 'intuïtieve layout van een scherm-interface' to 'intuïtieve layout van een scherminterface'.
2026-06-09 Enhance machine interface research documentation gedeeltelijk
    Added detailed sections on machine interface research, including elimination phases and prototype testing.
2026-06-09 Vervanging
    Te veel witruimte rond de afbeelding dus hier is de vervanging
2026-06-09 Revise pros and cons for arm mechanisms
    Updated the pros and cons for sliding and rotating arm mechanisms in the documentation.
2026-06-09 Fix image paths and update machine interface conclusion
    Updated image paths and added conclusion about the sliding + rotating arm.
2026-06-11 Add notes on measurement and arm movement
    Added notes regarding measurement relevance and arm movement speed.
2026-06-11 Revise notes and conclusions in development documentation
    Added notes on input measurement and arm movement effects. Updated conclusions on machine interface solutions.
2026-06-11 Revise notes on input measurement and arm movement
    Updated notes regarding the photo method and sliding arm performance in the document.
2026-06-12 Add Develop 3 section on design and user experience
    Develop 3 focuses on product design, materials, and user experience. It includes methods for determining desired experiences, exploring CMF variants, and conducting user research.
2026-06-12 Update materials list in BOM.md
    Removed several components from the materials list and updated links for others.
2026-06-12 Alle CAD files
    [Arm dicht lasercut - long side - 2x.dxf, Arm dicht lasercut - long top - 2x.dxf, Arm dicht lasercut - small side - 2x.dxf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]
2026-06-12 Enhance README with CAD file organization and details
    Updated README to provide detailed structure and descriptions of CAD files and prototypes.
2026-06-13 Test of de servo's werkten
2026-06-13 Schema's van de schakelingen
2026-06-13 Update README with servo and stepper motor details
    Added images and descriptions for servo and stepper motor setups.
2026-06-13 Create manual for latest prototype assembly and usage
    Added a comprehensive manual for the latest prototype, including required materials, electronic components, wiring diagrams, assembly instructions, and design principles.
2026-06-13 Add link to manual for final prototype in README
